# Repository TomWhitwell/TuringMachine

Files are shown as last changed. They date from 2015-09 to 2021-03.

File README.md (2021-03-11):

# TuringMachine Mark 2

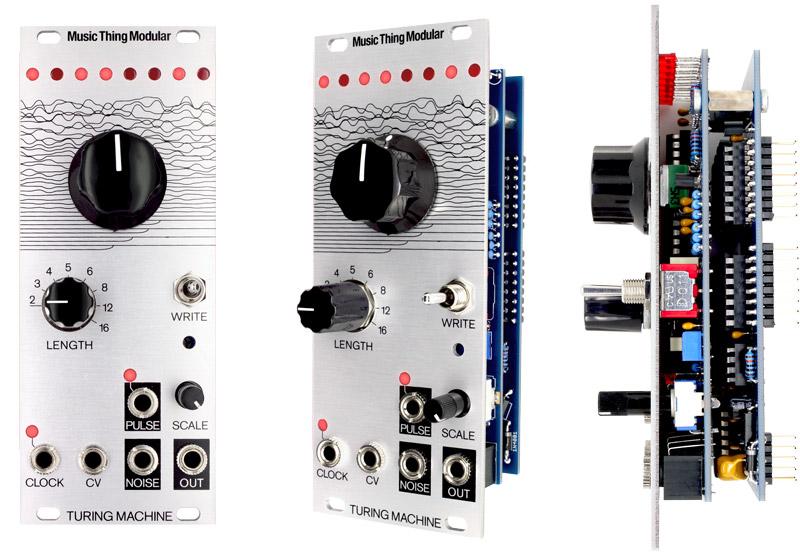
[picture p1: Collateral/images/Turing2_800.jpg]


Since it was launched in June 2012, the Turing Machine has become one of the most popular Eurorack DIY projects. It is a random looping sequencer that spits out basslines and melodies. It generates strings of random voltages that can be locked into looping sequences. 
These sequences can be allowed to slip, changing gradually over time. This module was inspired by the long history of shift register pseudorandom synth circuits, including the Triadex Muse, Buchla 266 Source of Uncertainly and Grant Richter’s Noisering.

[This video explains how the Turing Machine works.](https://www.youtube.com/watch?v=Le26BIqB8Y8)  

The 2016 revised Turing Machine has many improvements:  
- Rotary loop length switch 
- Pulse out
- Two boards, includes Backpack circuit to drive expanders (compatible with old Music Thing expanders)  
- Easier to build: a larger PCB in the same width, clock and noise circuits are more robust
- Noise level trimmer & reduced voltage in noise circuit to make circuit more robust with different noise transistors 
- Compatible with existing expanders 

*“I am interested in perceptible processes. I want to be able to hear the process happening throughout the music. To facilitate closely detailed listening a musical process should happen extremely gradually.”* Steve Reich, [Music as a Gradual Process](http://www.bussigel.com/systemsforplay/wp-content/uploads/2014/02/Reich_Gradual-Process.pdf), 1968. 

[Schematic](https://github.com/TomWhitwell/TuringMachine/blob/master/Collateral/PDF%20Schematics/TuringMachine2_Schematic_May2016.pdf)

Status:   
April 2016: Design files and Gerbers tested and prototyped successfully 

License:  
[CC-BY-SA](https://creativecommons.org/licenses/by-sa/3.0/)

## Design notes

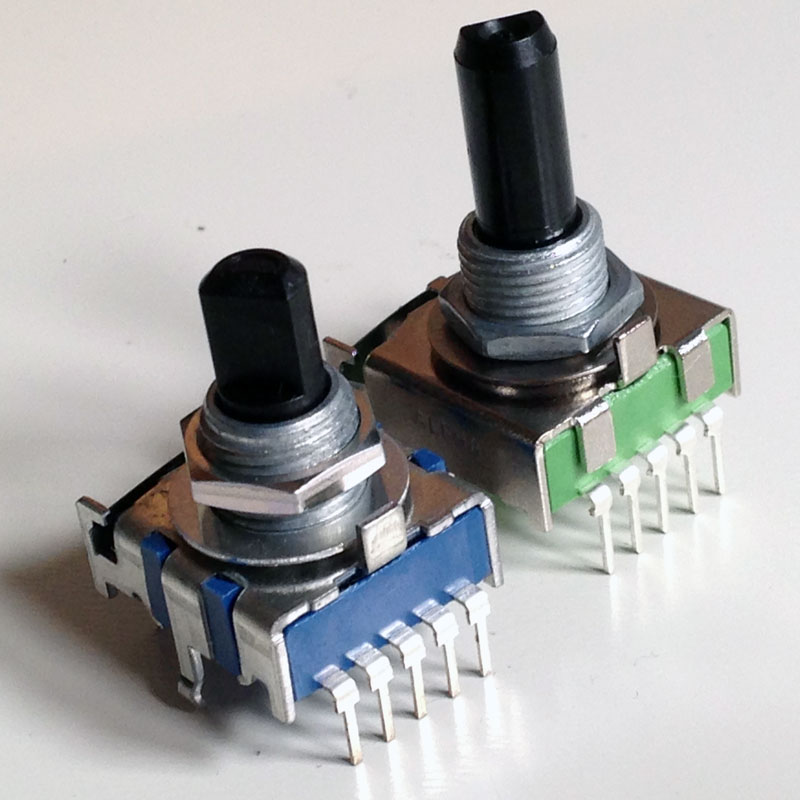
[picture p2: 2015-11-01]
Collateral/images/alps-alpha-switches.jpg

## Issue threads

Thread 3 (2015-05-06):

R5 is 51k on silkscreen, 50k on BOM

TomWhitwell, 2015-05-06:

TomWhitwell, 2015-07-25:
fixed

Closed 2015-07-25.

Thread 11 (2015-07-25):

Grounding issue - circuit only works with two cables, not one

TomWhitwell, 2015-07-25:
while in external case

TomWhitwell, 2015-07-25:
In external case

Closed 2015-10-24.

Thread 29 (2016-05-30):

Turing Machine won't power up.

stefanhelton, 2016-05-30:
Not sure what I may have done wrong, was hoping you could help me. After assembling the Turing Machine, I plugged it into a uZeus power module and nothing seemed to happen. When I sent a gate signal to the clock input and sent the out to an oscillator,  it triggered it in a continuous drone.  None of the LEDs are coming on, and none of the switches or potentiometers have any effect on the sound. Do you have any idea what my problem could be?

Thonk-Steve, 2016-05-30:
Best thing to start with is post some good photos of both sides of both boards.

stefanhelton, 2016-05-31:
Sorry if some of the board is hard to see, I'm having to do this from mobile and my camera isn't that great. Some of the solder points are a little sloppy, but as far as I can tell they all make solid contacts and don't bridge over to other solder points. I have access to a multimeter if that would help, I'm just not sure where to start checking.

stefanhelton, 2016-05-31:
Forgot the link to the pics, my bad

http://m.imgur.com/a/HUGIG

TomWhitwell, 2016-06-02:
The TL074 on the front board is upside down.
Curiously, I did EXACTLY the same thing while building a module this weekend. I spotted it, threw away the TL074 (you could probably just turn it round), got a new one, and installed THAT upside down too. Eventually I managed to put it the right way around (!) and it worked perfectly.

Closed 2016-06-02.

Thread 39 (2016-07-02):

diy osmosis

zaejin, 2016-07-02:
Hi, great fun building the kit but it seems there's a problem.
When it's attached to the power, it makes every socket in my modular output a clicky slow square tone.
Even on different modules. The other bits work okay when the turing isn't plugged in the power.

I'm using a synthrotek psu.
Cheers,
Victor.

Thonk-Steve, 2016-07-02:
I would start by using a multimeter to check if you have continuity on the
Turing power connector between -12v and Gnd, +12v and Gnd or +12v and -12v.

Sounds like you have a short circuit in the Turing build somewhere to me.
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

zaejin, 2016-07-02:
Hi thanks for your time.
There doesn't seem to be a short between those pins which I guess is where the whole of the circuit converges,
(i am a noob at this so I don't know where to look for shorts, those traces look awfully close).
I've had a look at all the solder joins and they seem ok.

Thonk-Steve, 2016-07-02:
Hi, do you mean you tested with a meter or visually? The short will present
itself at the header to the meter but physically could be anywhere on
either board. You can't do this test visually.
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

zaejin, 2016-07-02:
tested with a meter, yes. but I'm at passive mult level of skill here.

TomWhitwell, 2016-07-02:
I'd double check that all the chips are the right way round and in the right places

zaejin, 2016-07-02:
yeah they're checked to the build docs. all okay.

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

Thonk-Steve, 2016-07-04:
Ok I think best thing to do is take photos of both sides of both PCBs and
we can take it from there

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

zaejin, 2016-07-04:
Okay, taken some pictures as best I can without a tripod.
Many thanks for the effort.
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

swahananda, 2016-07-07:
It looks like your 1n4001 on the back board are both oriented in the same direction. This is no bueno as diodes only allow power to flow through one direction and your -12 rail is currently aiming back into your system. The one on the bottom left of your image needs to be reversed.

zaejin, 2016-07-07:
it works you f***ing wizard!! bit tricky resoldering the component but I managed it.
Thanks thanks thanks you efforts are appreciated thonk and friends.

Thonk-Steve, 2016-07-07:
Ah it was nice to come check up and find this :)
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

swahananda, 2016-07-07:
Oh heck yeah! Glad to be of some service! Now if only I can get my own Turings sorted, life will be even sweeter.

Closed 2016-09-15.

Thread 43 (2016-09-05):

No sign of life.

jestern77, 2016-09-05:
Assembled the complete kit as suggested in the docs. Seemed pretty easy. I plugged the TM (power + clock) nothing worked. Realized I forgot one 100nF cap on the ic (back) board. Soldered. Plugged in, no life. Checked all transformers to be correct and IC to be the right ones. Redid all solder points, still nothing. Sometimes when I unplug the power the two leds (clock and first bit) light up. Changed the TL074 (just in case) no sign of life.

Attached some pictures. Any clue? Maybe the lacking 100nF could have screwed up some IC? strange though...

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

TomWhitwell, 2016-09-15:
Can't see anything unusual in the pictures - have you made any progress? Does the clock LED flash when you connect it to a clock?

jestern77, 2016-09-15:
HI Tom, no unfortunately doesn't work. The led doesn't lit up but the noise output does output noise. So the power goes there. Maybe some burned IC?

TomWhitwell, 2016-09-15:
The clock input is the same chip as the noise generator, so it's hard to see how that could be. The 100nf would definitely not be a problem.
It's a mystery - are you able to try it in another case? Do you have a friend with a working Turing you could compare it with?
You could certainly try replacing the ICs, but it's an unusual case.

jestern77, 2016-09-15:
hmm I refilled some of the holes, still no sign of life. Checked the LED orientation. I can send it to repair to a friend and see what went wrong...

Closed 2017-12-19.

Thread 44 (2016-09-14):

Turing Machine mk2 error

paxxxx, 2016-09-14:
Hello guys! I just connect the turing machine mk2.

I put a square wave in clock , and the clock light its ok , same tempo than wave.
I get noise and pulse, but nothing comes from Out...i was following the calibrate video , and it seems that i should have sound from out isnt it?
Also... all the top lights are fixed all the time.

Anyone can help me on this?
thanks very much guys.
Picture attached.

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

TomWhitwell, 2016-09-14:
You won't get sound from Out, but voltages to drive an oscillator.

Lights will be fixed on until you put a clock in and put the main knob at 12 O'clock.

paxxxx, 2016-09-14:
Thanks for your reply Tom!

Now i connected the out to 1v Oct input of a synth, and then it sounds as loop...then i move the main knob at 12 o clock, and i see the lights moving , but after 2 or 3 compasses, all lights are gone and never come back!

Maybe im doing something wrong?? sorry if its a basic question.

paxxxx, 2016-09-14:
i mean, the clock still pulsing, but pulse output light are off now, and top lights are all off too.

paxxxx, 2016-09-15:
Nothing... The module accept the clock, and create some pulses and cvs, but after few seconds, all the top lights are off, the pulses lights are off, and dont create any cvs :(

TomWhitwell, 2016-09-15:
That sounds like a soldering error - somewhere you may have missed a pin, swapped a component or inserted a diode the wrong way around.

Closed 2016-09-15.

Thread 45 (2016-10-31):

Help appreciated with troubleshooting my build

mayk19, 2016-10-31:
I'm new to the modular world, just finishing my first 84hp rack. I love the idea of building something that I make music with so went for the Turing Mk2. Back in the late 80s I built my entire DJ setup from maplins kits, 100w mosfett amps, sound to light kits, cans for speakers and even cabs for citronics turntables (couldn't afford 1200s !)

However, a long time has passed since my last soldering forays and unfortunately my Turing doesn't work :-( bit of a cheepo soldering iron to start with so I'm thinking that's where the issues lay however, it powers up, all leds are lit (I need to re-confirm if clock is lit before I put the oscillator into it) but starting the Tuning procedure and there is no audio out at all. Can anyone help point me in the right direction to start trouble shooting? Failing that , is there a repair service out there at all ?

Pictures of my board attached.

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

mayk19, 2016-11-02:
I found a solder bridge between two pins on the IC "Shiftreg_Main" 4015 top two right ones. Waiting for a new chip socket to solder in as I couldn't get to the solder blob without removing the holder. Fingers crossed thats all it was.   Will update.

Closed 2017-12-19.

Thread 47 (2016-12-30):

Pulse outputs Failing

123gravy, 2016-12-30:
Hey,

 I have just put together the Turing machine plus volts and pulses expanders.  All working fine apart from the pulse output on the Turing machine itself and two outputs on the pulses expander (the '1+2' and '1+2+4+7'). There is no output from these at all. Has anyone experienced something like this? Or is there something I should try? Solder joints look ok

Thanks

TomWhitwell, 2016-12-30:
Check orientation of all the chips on the back PCB of the main Turing module. Try swapping the AND chips to see if that makes a difference

123gravy, 2016-12-30:
Hi Tom,

 Thanks for the reply.  Orientation of the chips are all good.  Which chips
are the AND chips?

Isn't it strange that both the 1 output and the 2 output are all good but
not the 1+2 output on the Pulses?

Cheers

On 30 December 2016 at 22:31, Tom Whitwell <notifications@github.com> wrote:

Check orientation of all the chips on the back PCB of the main Turing
module. Try swapping the AND chips to see if that makes a difference

—
You are receiving this because you authored the thread.
Reply to this email directly, view it on GitHub
<https://github.com/TomWhitwell/TuringMachine/issues/47#issuecomment-269761552>,
or mute the thread
<https://github.com/notifications/unsubscribe-auth/AXsIJGctYGebFNCVhT30W-qrve_1f9JZks5rNOucgaJpZM4LYHk_>
.

Thonk-Steve, 2016-12-30:
Photos of the build would help, did you also double check the soldering of the expansion header on the main module? Do you have any other expander modules like Volts, Voltages etc?

TomWhitwell, 2016-12-30:
You can also try connecting pulses to the gates header. That will tell you if the problem  is in the main module, or the pulses module.

123gravy, 2017-01-04:
Hi,

 Thanks for the replies.  Please excuse my slow reply, I was away from my rig for a few days.

I do have another expander, Volts.  Seems to be working ok.

The solder joints of the expansion headers look ok to me but I'll attach a few photos.

I attached the Pulses module to the Gates header on the Turing Machine and the Pulse output on the Turing Machine then works, but still not the two (the '1+2' and '1+2+4+7') outputs on the Pulses module.  What does that suggest there must be an issue with both the TM and the Pulses builds?  Sorry to be a pain

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

123gravy, 2017-01-04:
I double checked all of the expander headers and re-soldered a couple of pins that looked as though the solder hadn't gone through to the other side quite as well when you pry up the black pin support on the header.  Still all the same

123gravy, 2017-01-04:
I've checked all of the jacks on the Pulses with a beep test.  All fine.  Re-soldered the IC as it was a bit rough.  Still the same.  I'm convinced that it is just the Pulses module.  I just can't suss out which component...
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

123gravy, 2017-01-05:
The Pulse output on the Turing Machine also works fine without any expanders attached

123gravy, 2017-01-10:
I should also mention that the outputs of the Pulses do not carry pitch but they do give a signal.  I've been using them to trigger drums which works fine.  However when I send the signal to an oscillator they each trigger in only one pitch.  Every output has the same pitch except for output 1 which has a higher repeated pitch, no variation following the turing machine...

TomWhitwell, 2017-01-10:
Pulses outputs are triggers - normally low (below 1v) becoming high (roughly 8v) when they are active. They're not expected to have any pitch content.

123gravy, 2017-01-10:
Ah ok. I only got that impression from this video https://youtu.be/Le26BIqB8Y8 about 14 mins in. I can't see the full patch though.  So that's that query sorted. Thanks. Can you make any sense of the rest. (The 2 outputs not working on the pulses and the pulse output not working on the Turing machine only when the pulses is plugged in)?

TomWhitwell, 2017-01-10:
Sounds like a soldering problem around the chip on the expander

123gravy, 2017-01-10:
Ok cheers. I did touch up some soldering around the chip and nothing changed. It still could be better though so I'll try removing it altogether and starting fresh. Thanks

123gravy, 2017-01-10:
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
Hello again Tom.  OK so i re-soldered it again and this time also lost outputs 4, 2+4, and 4+7.  I touched it up again and managed to get it back to just missing the original 1+2 and 1+2+4+7.  As you can see from this photo I've made a dogs dinner of the PCB.  You can see some copper next to the IC.
 I'm wondering maybe if I've knackered the IC? Or now possibly the PCB?  Or both.  Would it be worth getting a new IC do you think?  Or have I killed this one?  Sorry to be a pain in the arse

TomWhitwell, 2017-01-10:
Hi, - that doesn't look great - I can't really tell from the pictures, but it looks like there could be any number of shorts between the IC pins. If you have access to a hot air soldering gun, lots of flux and soldering braid, it might be possible to clean it up, but tricky...

123gravy, 2017-01-10:
I do have a bit of flux and braid.  Yeah to be honest I haven't really been using the flux.  I'll give it a proper go again using those.  So you wouldn't be too worried about the exposed copper on the PCB?

TomWhitwell, 2017-01-10:
If it's just exposed, that's probably OK so long as nothing is shorting onto it.

123gravy, 2017-01-10:
Ok, thanks

123gravy, 2017-02-01:
Hey Tom,

 Cleaned up the IC.  Re-soldered like a machine! Same drama.  Re-soldered all resistors.  All working like a dream, Turing machine, volts and pulses.  Must have been a bad contact thing with the resistors on the Pulses.  Awesome kits! How annoying is ametures must be.  Cheers

Closed 2017-02-01.

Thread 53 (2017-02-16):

BOM xls missing 47k resistor

whodevil, 2017-02-16:
Hello,

I'm looking over the BOM and the PCB, and it appears as though the mouser BOM that is in xls format is missing a 47k resistor.

Thanks!

Thonk-Steve, 2017-02-16:
Hi, which BOM?

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

whodevil, 2017-02-17:
Hello, this is the one I'm talking about /Collateral/BOM/Turing v4 Mouser Export.xls
I think it is also missing two 1n4001 diodes and two ferrite beads.

whodevil, 2017-02-17:
It seems like this BOM is for a different project than the Turing Machine MKii. Here is what I have found missing so far:
- 47k resistor
- 2.2k resistor (9x)
- 1n4001 diodes (2x)
- two ferrite beads
- two fuses
- 78L09 voltage regulator (2x)
- 6 pin two row female socket (2x)
- 10 pin two row female socket
- 16 pin IC socket (x5)
- 14 pin IC socket (x4)
- 8 pin IC socket
- .1uf ceramic capacitor (8x) - There are 5 in the BOM but the build requires 13
- 100n ceramic capacitor (5x)
- hex stilts (2x)
- IC CD4050 (2x)
- IC CD4081 (2x)

There are 3 TL072 but only one is required.
There is an extra 10k resistor.
There are three 2N3903 transistors but only one is required.

It would probably make more sense for me to fix it and create a pull request.

Thonk-Steve, 2017-02-17:
Ah ok, yeah use this one - https://docs.google.com/spreadsheets/d/1FUUejrNd6qe-PUmlLi0BAgiGKWX9DxQH3Jt5qFOxPAQ/edit?usp=sharing

whodevil, 2017-02-17:
@Thonk-Steve Thanks! I think that document should be linked in the README.md or something. At the very least remove the old BOMs from the repo.

TomWhitwell, 2017-02-19:
Thanks, have now updated with a link to the correct BOM from Google Docs

Closed 2017-02-19.

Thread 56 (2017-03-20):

No sound at output, no action on Leds

zoth4355, 2017-03-20:
Bought the turing from Thonk (complete kit with volts and pulses). The unit worked for months, then I sold to a buddy. Worked fine until a couple of weeks ago. The unit stopped locking and the seq leds  stalled, clock input doesn't seem to move anything or when it does it hangs almost immediately. He brought it back to me to check it out. Tried clocking it from 3 different sources (ALM's Pamela's, 4MS QCD and an SSF Square Wave. clock LED seems to work (does flicker), pulses LED is always lit (?), noise output works, and I hear nothing from the output (found this while calibrating the unit). I'd appreciate some help resolving this issue. Thank you.

TomWhitwell, 2017-03-20:
If it was working but is now not working, could it have suffered some strange voltage incident; it's protected against reverse voltage, but could have been something else. Swapping the chips would be one way to find out, start with the TL074 on the front PCB - that handles the clock. Alternatively- could it be a cold solder joint somewhere?

zoth4355, 2017-03-20:
Swaped the TL074, did get some action for a couple of second then stopped. I tested the scale knob and it does work, but the sequnce hang hafter little time, odd. I'll go back to my solders, hopefully it's a cold joint. Thank you for the super fast reply Tom.

TomWhitwell, 2017-06-21:
Hi, did you make any progress with this?

zoth4355, 2017-06-21:
Hi Tom,
Thanks for asking,
I've tried every trick in the book, reflowing the solders, recalibration and swapping some IC's and other stuff, still unstable, sometime locked for 10-15 mins when lucky (this was tested without the expanders attached). I got frustrated and bought new pcb's from Steven and ordered new components from mouser. The original unit, I think, had a bad trace but I can't confirm, I just couldn't find what went wrong, why it got crazy after a few month of working properly. 
Sold the fresh new unit to a buddy. Still stable at this time. All IC's are TI went for quality parts, took more care than usual when manipulating the pcb's and advised my friend to be careful when connecting the pulses and voltages. Now he want's me to order and build a vactrol mix for him... 
Might it strain the Turing module to have so many expanders attached to it? Don't see why but might as well ask.
Thanks
Pat

    Le mercredi 21 juin 2017 3h10, Tom Whitwell <notifications@github.com> a écrit :

 Hi, did you make any progress with this?—
You are receiving this because you authored the thread.
Reply to this email directly, view it on GitHub, or mute the thread.

Closed 2017-12-19.

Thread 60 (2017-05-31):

No Clock LED, No Output, build not working

bertog, 2017-05-31:
Hi,

I've just finished my second TM build and this time I've some issue. The module power up but when I plug the square signal in the clock input there's no LED activity or audio output (seems something but very very very low). The DAC0800 become also immediately very hot. Some advice to begin some trouble shooting?

Some picture of my build:

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

Thank you very much. Guido Bertolino

Thonk-Steve, 2017-05-31:
Do you still have your successful build?
Have you checked with a multimeter for a short between +12v and gnd, or -12v and gnd?

bertog, 2017-05-31:
Hi Steve,

Yes I've access to the other build.

I've checked now and I've no short.

G.

Thonk-Steve, 2017-05-31:
I would suggest trying a combination of front and rear PCBs with the working build, then at least you can find out which board is faulty? You tested for shorts with the defective PCBs mated together?

bertog, 2017-05-31:
Thanks for the help.

I've matched the rear PCB of successful build with the jack pcb of the faulty and everything is working. I've successfully calibrated the module.

So the problem is on the rear PCB.

I've check for short with the mated PCBs and now only on the rear, but seems there's no shorts

G.

bertog, 2017-05-31:
Ok Steve,

I've founded the problem ... there was a small piece of lead touch one of the IC solder joint ...

I've removed it and now is working ...

Sorry and thank you very much for the help ... I'm newbie so I fall in panic very early, but tonight I've learned some troubleshooting ... Thanks again :) Guido

Thonk-Steve, 2017-05-31:
great, just talking about and trying new angles often shakes these things out :)

Closed 2017-06-21.

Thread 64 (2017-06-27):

Clock LED doesn't trigger and all lights come on at the top, don't change.

calmoo, 2017-06-27:
So i finished the build today. I've double checked all components and solder joints.

When I turn it on, all the lights at the top of the Turing Machine come on. The clock LED doesn't respond to a clock source at all. Sometimes when I turn it on, the top left LED stays off while the others stay on. The knobs don't change anything. The noise output works.

Not sure what I'm missing?

TomWhitwell, 2017-06-27:
Check around the TL074 on the front board - that's the clock circuit - it's possibly a missed solder point there or on the clock input. If noise is working, then that TL074 is working - receiving power etc, so it's likely to be a missing solder joint or component.
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

calmoo, 2017-06-27:
Figured out that the clock source I was feeding from my phones LFO
generator volume  was too low. Daisy chained it from a doepfer envelope
generator and it worked a charm. Thanks Tom!

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

Closed 2017-08-03.

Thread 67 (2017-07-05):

can't calibrate, get a kind of sinus sound...

Latzenpratz, 2017-07-05:
Hi!

just finished my build. I'm trying to calibrate, but the main pot and the calibration pot don't do anything. Length, write and scale seem to work. I here something like a sine wave played with  the set length, but no randomness.

Thonk-Steve, 2017-07-06:
Would it be possible to upload a video demonstrating your problem?

On Wed, Jul 5, 2017 at 8:22 PM, Latzenpratz <notifications@github.com>
wrote:

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

Latzenpratz, 2017-07-06:
Thanks for the quick response!
I'll try to make a video next weekend...

Latzenpratz, 2017-07-13:
Hi!
I noticed that the Turing triggers my maths without connecting it (i can hear the turing output from the maths output). The only connection between them is the power board...
So i'm to scared for now to reinstall the turing and make a video.
Maybe you can see an error on the pics:
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

Latzenpratz, 2017-07-21:
On my MDLR busboard the -12v LED doesn't light up if i install the turingmachine, so it seems there is a short-circuit or something... help...

Thonk-Steve, 2017-07-21:
Use a multimeter continuity tester to see if you have continuity between:

+12v and gnd
+12v and -12v
-12v and gnd

On Fri, Jul 21, 2017 at 4:05 PM, Latzenpratz <notifications@github.com>
wrote:

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

Latzenpratz, 2017-07-21:
yes, continuity between -12v and gnd

Thonk-Steve, 2017-07-21:
yeah I would start looking along the -12v lines and see if you have any
shorts

On Fri, Jul 21, 2017 at 4:11 PM, Latzenpratz <notifications@github.com>
wrote:

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

Latzenpratz, 2017-07-21:
yes the short must be on the board with the music thing print. i'll do my very best ;-) THANKS!

Thonk-Steve, 2017-07-21:
yeah it is worth taking the PCBs apart just to double check which board
it's on.

On Fri, Jul 21, 2017 at 4:16 PM, Latzenpratz <notifications@github.com>
wrote:

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

Latzenpratz, 2017-07-21:
I can't see any visible short, where are good points to break the circuit to narrow down the place of the short?

Latzenpratz, 2017-07-25:
Found it!  :yay:
One diode was faulty, after removing it the turing machine works!

Closed 2017-07-25.

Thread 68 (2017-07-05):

No Random output

Paulhamlin, 2017-07-05:
Hi Tom / Thonk

Thanks for putting together a great build with instructions, its been a breeze up untill now. I've come to the end of my build and all appears to be working well and behaving as should apart from the random voltage out. The scale knob adjusts pitch correctly and the lights displaying the cycling of notes however the outputted pitch is always the same.

Have you any ideas about this or where would be a good place to start looking? Ive double checked solder joints and will triple check in the morn just to be sure.

Thanks
Paul

Thonk-Steve, 2017-07-05:
Hi Paul, is the white noise output working?

Paulhamlin, 2017-07-06:
Hi Steve, thanks for getting back to me - yes im getting white noise when connected directly to an output.

Thonk-Steve, 2017-07-06:
Hi Paul,

Is the white noise output a relatively 'normal' volume level? not super
quiet or anything?

You're sending the main output to the 1v/oct input of an oscillator to
test? what are you clocking it with?

Steve

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

Paulhamlin, 2017-07-06:
Yeah the white noise level seems good.

I'm clocking with maths that is going into the 1v/oct on braids. Just metered the output with the scale knob on zero and the module cycling and the output shows a steady 0.00v - moving the scale knob moves this voltage up however there is no fluctuation in voltages.

Cheers

Paulhamlin, 2017-07-06:
Spent a few hours earlier today checking over the board / checking for shorts and making sure that i didn't put anything in incorrectly and I'm still getting the same behaviour.

From looking over the schematic it looks like the DAC chip is responsible for the output, could it be possible that its faulty? Ive searched high and low on the Muffwiggler forums and can't seem to find anyone else with this problem...

Any help or advice would be much appreciated!

Thanks

TomWhitwell, 2017-07-13:
Sounds like a problem with either the DAC or the TL074. If you have the clock and noise working, they're both on the TL074, so it points to the DAC, or the surrounding infrastructure: the TL431 voltage reference, R28, R27, C9, R26.
Completely unchanging output means it's not getting partial data, so the 8 data lines into the DAC can't be the fault. Could be a bad DAC chip, or a soldering error  / short somewhere around there.

Paulhamlin, 2017-07-19:
Hi Tom,

Thanks for the advice - managed to solve it after metering between the parts you listed.

Turned out a pad had somehow got damaged and wasn't flowing to the PCB solder - putting a cable link in got it up and running, not the prettiest but got it working correctly!

Thanks again
Paul

guidozzz, 2019-01-20:
Thank you Tom (and Paul for starting the thread with exactly the same issue as me) !
A connection between R27 and TL431 wasn't working. I have done a wire link and seems to work fine now!

Closed 2017-07-19.

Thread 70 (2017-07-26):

Led B4 not working

Rolf102, 2017-07-26:
Hi,

I finished my Turing machine mk2 today it is working perfectly except for one led, i checked the schematic, it is led B4.
I tested the LED it is not broken, i reflowed all the joints on both boards with no effect.
While it is a minor defect the perfectionist in me cannot overcome this.

Please help

TomWhitwell, 2017-07-26:
Did you check the LED is not reversed?

Rolf102, 2017-07-26:
unfortunately no all the leds are in the same orientation

Rolf102, 2017-07-27:
i checked all the components and found that i soldered one of the 78l09 with the flat face to the wrong side, i fixed it but the led still does not light up, should i replace the 78l09 for a new one?

Thonk-Steve, 2017-07-28:
do you have a multimeter? can you check if the new 78l09 is putting out 9V?

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

Rolf102, 2017-07-29:
both voltage regulators are putting out 9 volts

Rolf102, 2017-07-29:
i fixed the problem, the trace from the led negative pole to the resistor is broken.
i soldered a copper wire from the led to the resistor

Closed 2017-08-03.

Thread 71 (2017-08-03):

TuringMachine not working at all

dorkajef, 2017-08-03:
Hello,
Finished My DIY for the Turing machine yesterday. But it did not show any traces of life -> no noise, it did not blink lights, did not effect the OSC when patching, did not react to clock signal.
I did check My solders couple of times, double checked also the parts -> everything should be ok (but after one check the upper light when on ((but no reaction to clock, etc...) -> and when I unplug the device and put all the nuts on -> again no lights.
I know that My solder is not the best A+, but all My DIY units have worked until now.
Would you have an idea what´s wrong?

Best Regards
Thomas
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

TomWhitwell, 2017-08-03:
Hi, sorry to hear that. When I have problems like that, it's often because I've done something extra stupid - like not turning on the power, not connecting the other end of the power cable etc.
One thing you could try is - if you have  multimeter - checking that you're getting the appropriate power to the chips - i.e. separate the boards, plug the back board into power, and check there is (roughly) 24v difference between pin4 (black probe) and pin8 (red probe) on the little TL072. That will tell you if there's a basic problem with power. If the back board is OK, carefully check the soldering on the connector pins between the back and front boards - if the front board isn't getting any power, you'd get the symptoms you describe.

dorkajef, 2017-08-03:
Thanks Tom for the Quick answer.
Gonna try that tonight after I come home.
Best
Thomas

dorkajef, 2017-08-03:
Hello,
I think I may found the problem. There is a shortcut in the six pin header (the middle one on the back board). Could this mistake have fried my parts?
Thanks!
-Thomas

TomWhitwell, 2017-08-03:
Possibly not - that connects +12 to -12v, which I'd imagine would cause your case power supply to shut down quite fast - fix it, check there's no more connectivity, and test to see

dorkajef, 2017-08-03:
Hi,
Just to make sure that we are speaking from the same part...
I removed the connection part, and try to clean the area, but if I assume right the PCB has jumpers between pins 1&4, 3&6, and on the other side 2&5 (but I quite n00b with these things;).
I´m just wondering because my meter is beeping with these connections (also with the upper PCB).
Best Regards
Thomas
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

TomWhitwell, 2017-08-03:
This is how they're connected:
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

dorkajef, 2017-08-03:
Sorry my bad, I did mistakenly assume who those are counted -> so no shortcut there, they where as they should be.
I did also measure the power as You instructed -> and I got a reading of about 25 Vdc and 52 Vac.
Did also solder all the connector pins newly (at that moment I mistakenly noticed that so called shortcut). So any ideas?
Best Regards
-Thomas

dorkajef, 2017-08-03:
Hi,
I did also test the connection pins while the boards are connected, the connections works - but I also noticed that on the upper board has also an connection beteeen +12 & GND somewhere (this is normal, I suppose).

-Thomas

TomWhitwell, 2017-08-03:
No, there shouldn't be a connection between +12 and GND - that would also the problem.

dorkajef, 2017-08-04:
Ok, I´m on the trace.
I did try to find out where the GND goes (but can´t see it from the PCB), and I´m not enough seasoned to read it from the schematics. So if you can advice Me (then I maybe could find the shortcut).
Thanks
-Thomas

TomWhitwell, 2017-08-04:
GND lives on the ground plane - it's all the copper on the bottom that isn't part of another trace:
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

dorkajef, 2017-08-04:
Ok, thanks.
So non of the GND points should make a connection with +12?
-Thomas

TomWhitwell, 2017-08-04:
Definitely not

dorkajef, 2017-08-04:
Hi,
Have been looking for any solder shortcuts (could not find any). I even removed some parts (all capacitors but not: c17, c14 & c9).  The IC´s I removed in the beginnin of this operation.
Still a shortcut when measuring Link2 pins 6&4 (+12 & GND).
Any idea where / what path I could try to find next?
Thanks for the help.
-Thomas

TomWhitwell, 2017-08-04:
Do you think the back board (with the power connector) is OK? Is that's where you tested the PCB voltages on the TL072?

Separate the boards, remove the two ICs from the front board, and see if there is still a short between +12v and GND

dorkajef, 2017-08-04:
Yes that is what I did. I assume that the back board was ok (measured the voltages as described -> ok), the pins had no short between the pins (when measured the back board separate)- > So I´m quite sure the problem is on the front panel.

Closed 2017-12-19.

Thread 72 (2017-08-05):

Short around power input.

foenzie, 2017-08-05:
Hi Mark,
First of al this is a great kit to build. Very clear documentation! But somehow i messed it up a bit. After finnishing the module I connected the power the wrong way around.. but only for like 2 sec. Then I connected it the right way around. Smoke started coming between the  +12 volt and the big fuse pcb trace. Elektricity finds the shortest way right, after measuring, there is a short between al ground and +12 volts. I cannot find any shorts on the board. Removed all IC and top board. Still shorts. I suspect the 10 pin power is somehow shorter, but all grounds to +12 seems unlikely? Thanks in advance. Funs

_Sent from my OnePlus ONEPLUS A3003 using [FastHub](https://play.google.com/store/apps/details?id=com.fastaccess.github)_

foenzie, 2017-08-05:
In my frustration I cut both rectifying diodes and one bi-polar capacitor. On this picture is clearly seen where the short is.

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

foenzie, 2017-08-06:
Hey Tom,

After some troubleshooting the board some more I found my short. In the picture below you can see exactly what part is shorted to ground. I strangely enough could not find any visual conformation from this short.  After cutting the PCB trace I found out this part was shorted and made a simple bypass (Removing all power pins did not remove the short). The Diode and fuse are fine I don't know how this is possible. But anyway thanks for the possibility to ask questions!!! Keep on building!

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

Closed 2017-12-19.

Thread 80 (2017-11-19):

Module partially not working

Stahlmotte, 2017-11-19:
Hi,
first of all: I´m not an expert in DIY modules. :-) So it would be great to get a little help. Maybe this is also something that happend in the past and a quick fix.

At the moment noise out works and all the LEDs (besides the first one) in the top row are on permanent. Nothing else is happening.

I checked for solder joints and stuff like that. I also checked the placement of the items. No luck so far.

So a little help would be great!!

Thanks in advance

Alex

TomWhitwell, 2017-11-19:
Hi Alex, sorry to hear that.
What are you using to clock the module?

Stahlmotte, 2017-11-19:
Hi Tom,
thank you for the quick reply. I tried a the Black VC Clock Module von Erica Synth and also Clock signal via uMidi. Anyway, sending a clock signal does not change the behaviour anyway. With or without clock signal.

TomWhitwell, 2017-11-19:
So your issue might be around the clock input - if the clock in doesn't flash the LED above the clock socket, that is definitely the place to start looking - check for missing solder joints or IC in the wrong way around.
I've often built a whole module, found a weird fault, then discovered I missed a couple of solder joints on sockets or ICs.

Schematics are here: https://github.com/TomWhitwell/TuringMachine/blob/master/Collateral/PDF_Schematics%20/TuringMachine2_Schematic_May2016.pdf
If the noise output is working, then the TL074 is alive (i.e. connected to power and the right way around) so it could be a connection to it, or one of the other components.

Stahlmotte, 2017-11-19:
Hi Tom,
tried to find all faulty solder joints in the last days and also today. Sure, i might be missing something. :-) Anyway, do you think it could be also a faulty IC? Thinking of ordering and swapping them if this could also be a possible option.
Best
Alex

TomWhitwell, 2017-11-19:
If you don't get a flashing LED above the clock in when you input a clock, that along will mean the rest of the module won't work - everything else could be perfect. The only IC involved in making that LED flash is the TL074 on the front board, and if you have noise, that IC is at least partly working.
In short - I think there's a faulty connection or a misplaced component somewhere here:
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

Stahlmotte, 2017-11-20:
Tom,
thank you again for your help. I really appreciate that! Yesterday i resoldered several joints on the board. Now, when powering up the module the LED flashes once at least. Everything else is still the same, but i will try to wirk through all the joints again. Hopefully this is the solution!
Best
Alex

Closed 2017-12-19.

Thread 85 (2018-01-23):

Powers on but not much else

schrickvr6, 2018-01-23:
Hi Tom,

I'm a relative noob to DIY and modular so please bear with me, I bought panel and PCB so there's every chance I've bought an incorrect part.

Basically it powers on ok, it may be inconsequential but sometimes all of the top row of LED's light up and sometimes a few don't. I'm getting no output (except a tiny bit of noise when I adjust scale), no movement or randomness but most tellingly it seems no input on clock, I've tried a square wave as in the calibration video and a gate from a beatstep with no response or clock LED activity.

In the way of fault finding I've reflowed everything, reseated IC's and swapped matching pairs, I've also measured all the resistances which tally with marked values except R10 which measured 83k instead of 100k, but various people on Facebook have reassured me that should be normal.

Any thoughts on where my problem may lie or how I should start/continue fault finding?

Cheers.

schrickvr6, 2018-01-25:
Please ignore (for now), I'd fitted a 68ohm instead of 68k right next door to r10, I don't have a spare to confirm this is my only issue but will close this if it works when my resistors arrive.

TomWhitwell, 2018-01-25:
Sorry to hear this, Yes, R10 as 68R vs 68K that would do it - I was going to suggest you look at the TL074 on the front board, but if you're pulling the clock to GND you won't get much joy.

Closed 2018-01-25.

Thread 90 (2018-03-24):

expander pulses 5 always pulsing, just like the clock source

indraperkasa, 2018-03-24:
Hi, i've built my turing machine and all the expanders few months ago, and its been working just fine. until recently i just noticed my pulse expander, on the pulse 5 is ticking exactly like the clock input on the main turing machine. from my understanding, it shouldn't do that (or am i wrong?).
the rest of the pulse working normally, have the same LED movement just like the LED from the main turing machine. i have all expander connected to the turing machine.
i try to switch, connecting the pulse expander to the gate connector (instead of pulse connector) on the back of the turing machine, and it work normal, the LED on turing machine reflected the same movement like in the pulses expander. so i suspected, there's a problem in the pulses connector at the turing machine, but i don't know what to do about it.
any idea what is broken? or maybe should i replace any IC?

thank you.

jstamant, 2018-03-24:
@indraperkasa Very good troubleshooting on your part. From what you're telling us, I'm comfortable in saying that there's no problem with the pulses connector.

Here's what I'm suspecting:
- Pulse 5 is shorted to 12V
- One of your 4081 quad AND gate ICs are defective.
- One of your 4015 shift register ICs are defective

Is the 5th LED on the Turing Machine always lit?

Try swapping the two 4081 ICs on your Turing Machine to see if the problem moves from pulse 5 to pulse 3. If it does, the 4081 that had pulse 5 on it is defective.

You can also try swapping the two 4015 ICs to see if that clears the problem.

If after you've swapped the two 4081 ICs, and the problem still registers on pulse 5, you'll have to start checking some voltages and continuity. First check the continuity on all the pins of the 4081 quad AND gate chip that carries pulse 5. Make sure that each pin on the chip has continuity to where they're supposed to go, and not connected to +/-12V or ground if they're not supposed to. Pin 8 on the 2nd AND gate IC (closest to the board edge) should have continuity to pin 4 on LINK3, pin 13 of the main 4015 shift register IC (closest to board corner), and should NOT have continuity to the +12V rail.

If all that still doesn't shed some light on your issue, check the voltage on pulse 5's AND gate inputs. Sounds like pin 8 with the B4_BACK signal is stuck high, and is just passing through the clock.

indraperkasa, 2018-03-25:
@jstamant hi Justin, thank you so much for the quick response.
the 5th LED on turing machine doesn't always lit, only on the pulses expander.
another thing i noticed, if i hold down the toggle write switch, all the LED goes off, except the LED 5 on the pulses expander, which pulsing at the same rate with LED clock input at the turing machine.

i've tried swaping the the two 4081 IC, didn't make any different. same result with the swapping of the 4015IC.
forgive me, since i'm a very newbie, don't really know about this electronical stuff, just got into soldering when i start to play modular a few months ago. i don't really know how to check voltages and continuity. if you don't mind, maybe can you guide me? i have a digital multimeter. i've been youtubing on how to do it, just not really sure if i was doing the right thing.
let say, if the Pin 8  on the 2nd AND gate IC4081 doesn't have continuity, what should i do next?

and about your last suggestion, can you guide me how to do it? checking the voltage on pulse 5's AND gate input (i don't know which one..). and if the pin 8 with the B4_BACK is stuck high, what should i do next?

thank you.

jstamant, 2018-03-25:
No worries, @indraperkasa.

You'll need to refer to the [schematic](https://github.com/TomWhitwell/TuringMachine/blob/master/Collateral/PDF_Schematics%20/TuringMachine2_Schematic_May2016.pdf) for the remainder of your troubleshooting. Also, downloading Autodesk's EAGLE will let you open the `*.brd` files located [here](https://github.com/TomWhitwell/TuringMachine/tree/master/Hardware) to get an x-ray view of the board, which you might find helpful for troubleshooting.

When you're checking continuity or checking resistance between two points, you need to have the board powered off. With your multimeter set to measure resistance, touch the two probe ends together, and make sure the multimeter reads close to 0 ohms. Next, take a spare resistor and measure its resistance. If the multimeter is reading the right value, then you know your multimeter is working, and you can proceed to checking continuity and voltages.

Again with your multimeter set to measure resistance, touch one probe to pin 8 of 4081 IC closest to the board edge, and touch the other probe to one of the +12V pins on the power header (opposite end of where the red strip goes). The multimeter should read "OL" or something similar indicating that the two points are not connected. Then do the other resistance/continuity checks with the other pins I mentioned. i.e. from pin 8 to LINK3's pin 4, and from pin 8 to pin 13 of the 4015 IC. All these pins are connected, so they should read something close to 0 ohms on your multimeter. Sometimes you have to press the probes hard to penetrate a thin layer of oxidization and/or flux to get a reading at all.

After you've done that, you can check voltages with the board assembled and powered on. Keep the front panel off the Turing Machine until you've confirmed that it's working. This time, to check that your multimeter reads voltages correctly, measure the voltages at the power header, because you *know* it carries +/-12V and 0V, or your module wouldn't power on. Placing the black lead on a GND pin, and the red lead on a + pin should read 12V. Then trying the red lead on a - pin should read -12V. Good, now you've confirmed that you multimeter is fine. Keep the black lead on the GND pin, and place the red lead on pin 8 of the 4081IC that's closest to the board edge to check the voltage on that pin. It should read 0V if there's no pulse on LED 5 on the Turing Machine. It should read 12V if there IS a pulse on LED 5 on the Turing Machine. From what you're telling us, it sounds like the voltage is *always* 12V, but we need to confirm that by measuring it.

indraperkasa, 2018-03-26:
@jstamant hi Justin,
thank you so much for writing this step by step, really appreciated it.
i did some test based on your guide.

the results are:
pin 8 of 4081IC closest to the board edge to +12v = approximately 6 mega ohm
pin 8 of 4081IC closest to the board edge to LINK3's pin 4 = approx. 18 mega ohm
pin 8 of 4081IC closest to the board edge to pin 13 of 4015IC = approx. 6 mega ohm

and with the board assembled and powered on,
pin 8 of 4081IC closest to the board edge with ground pin, reads 0v when LED 5 is off on turing machine, also reads 0v when the LED 5 is on.

indraperkasa, 2018-03-26:
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
just to confirm if i did test the right pin, here i attach the photo, i put the red circle for the pins that i think the one that you refer to..i hope its the right

jstamant, 2018-04-01:
@indraperkasa How confident are you with your use of the multimeter? The pins you outlined in your picture are the right ones, so you were taking measurements on the correct pins. I was hoping on getting different results than you indicated, though.

I was expecting pin 8 of the AND_2 chip to be either shorted to the +12V rail, or at least showing a voltage >+8V at all times (the 4081 IC closest to the board edge is named AND_2, the other 4081 IC I don't care about is named AND_1). You indicated that the pin shows a crazy-high resistance to +12V, meaning they're not connected, and that the pin is always showing 0V while running. If that pin shows 0V, then LED 5 on the Turing Machine should be off. Whenever it shows a voltage, LED 5 on the Turing Machine should be on.

Then, pin 8 of the AND_2 chip is supposed to be connected to LINK3's pin 4 and pin 13 of the main 4015 shift register, i.e. showing ~0 ohms. According to your measurements, in the mega-ohms range, they're not connected.

Let me know what you think of these results.

indraperkasa, 2018-04-02:
hi Justin,
i'm pretty confident with the result form the multimeter, i've checked it several times and the result is pretty much the same.
however there's bad news, i might damaged the module during the testing voltage procedure. i accidentally put the black lead from the multimeter (slip from my finger) in the -12v pin, and it causes spark a few times.
now, when i try to input a clock, the LED on turing machine doesn't even do random pattern anymore. it still receive clock pulse, but when i hold down the write toggle, after all the LED off, it remains off all the time. also if i hold up the write toggle for once, one LED show up, but that's it, only that one LED run across the all the 8 LED, looping.
i've been thinking, maybe just gonna let this one go..

jstamant, 2018-04-02:
Ok, no problem: a little spark is nothing we can't fix.

Where did you short the two pins? On the power header? Or was it one of the ICs? If you shorted on the power header, the damage would sooner be to your power module. If you shorted on an IC pin, that IC could be blown.

Did the spark appear on your test lead, or was it a component that sparked? Did you smell smoke when this happened? Magic smoke is the telltale sign of a failed component.

As for measuring the voltage on LED 5, that suggestion is still applicable. You can still check the voltage on that. It sounds like you can also troubleshoot the original issue with pulse 5 regardless of this other issue.

indraperkasa, 2018-04-02:
the sparks was on the power header. and it did make my power module to stutter, the +12v led lights blinking rapidly for a moment, and then back to normal.
thanks so much for the suggestion, i'm gonna try it again.

indraperkasa, 2019-06-13:
hi, just wanna say i finally solved the problem after abandoning it for more than a year. turns out the pin 8 iC 4081 (close to the edge) didn't connected to where it supposed to, turns out there's a scratch in the pcb, that broken the Via connection. so i solder a wire from pin 8 IC 4081 (close to edge) to the pin 5 IC 4050 (close to the edge). and now its working.
just wanna say thanks for your help, i learnt alot from debugging this, i feel a little bit confidence now on troubleshooting. and i'm getting more familiar with eagle file, such a convenience way.
thank you.

TomWhitwell, 2019-06-13:
So glad to hear it worked, @indraperkasa

Closed 2019-06-13.

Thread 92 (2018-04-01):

Turing Machine Dropping Notes + LED 2 out

BlipSqueek, 2018-04-01:
I have 2 issues with my build. I have built many modules so I'm not new to this, but I am also not someone who is good at troubleshooting circuits.
1) LED2 is out, but I do appear to be getting notes from 2
2) The turing machine will drop notes. If I have the main pot at around 3-4 o-clock it will cut out periodically, It always comes back within a second or 2 but it drops out pretty consistently. Maybe once every 5-10 seconds.
Here is a zip of the audio file ( won't let me upload wav files)

[TM Drop Outs.zip](https://github.com/TomWhitwell/TuringMachine/files/1866300/TM.Drop.Outs.zip)

jstamant, 2018-04-01:
If LED 2 is always off, the LED could be soldered on backwards. But don't remove it just yet. Try checking the voltage across that LED's leads when you suspect it's supposed to be lit. You should see ~2.2V when the LED is on. When the LED is supposed to be off, you should see 0V across the leads.

Or trying something else: measuring voltage from the + lead of the LED to ground, you'll see ~12V when it's supposed to be on, and 0V when it's supposed to be off. If you have it soldered backwards, you'll still see the same 12V/0V voltages.

As for your 2nd issue, how do you have your Turing Machine patched when you see this problem? Have you successfully calibrated your Turing Machine? And just for speculation, the Turing Machine doesn't produce notes, it produces random voltages. Your audio file sounds like you're clocking the TM at an audio frequency, and running the OUT jack right into your recording device or speaker, so I would expect it to behave as it sounds in your recording. Occasionally the TM might randomly clock in a set of all 0's, so there would be no change in output voltage i.e. no audio waveform to hear.

BlipSqueek, 2018-04-02:
Thank you for the help.
It appears that the only thing wrong then is the LED. It calibrates fine.
I tested the voltages. On the LED's ( + to -) I'm getting 1.69V on the working ones and nothing on the one that is out. Going to ground I get the expected 12V on all LED's. Did I put the LED in backwards? I triple checked and was sure they were all correct.

Closed 2018-04-02.

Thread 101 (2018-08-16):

No randomness

eliasbagley, 2018-08-16:
Hey guys!

I'm having some issues with the main randomness and length knob not affecting the behavior of the module at all. Hopefully you guys can point me to the part of the circuit that might explain the issues I'm having.

The issue is that no matter how I turn the main randomness knob (or CV input) or the length pot, it doesn't affect the output at all. I _can_ get values out of the output when I use the write switch, however. The write switch seems to be "sticky", in the sense that if all the lights are off, and I insert a single bit with the write switch and then release it back to the center off position, it will continue to insert bits from the left, as if I were holding the write switch up. No 0 bits ever get inserted again, until I manually write it in by flipping the write switch down. The same "sticky" behavior happens when I write a 0 - 0's fill in from the left as if I were holding the write switch down, even when I'm not. I don't think this is an actual issue with the switch though - I'm guessing that the part of the circuit that is doing the randomness and flipping part isn't working as it should, but I don't really understand that part of the schematic to debug it further.

I'm unable in any scenario to get bits to "wrap around" from the right to the left. Which part of the circuit controls this randomness and wrap around behavior? I'm guessing the issue is in there somewhere.

Here's what I think I know from the parts of the circuit that are behaving correctly -
1) Clock circuit works. The LED blinks and when I use the write switch, the top LEDS blink along with the clock.
2) Noise circuit works. I hear a strong white noise sound from the noise output, which is attenuated down to inaudible when I adjust the trimmer pot with a screwdriver.
3) Write switch works. Flipping it up writes a value into the left bit, although it's "sticky" - I don't think this is an issue with the switch though.
4) Scale pot works
4) DAC seems to work - the pitch of the output does change when I manually write bits with the write switch, and corresponds to the binary value indicated by the top LEDs.
5) Pulses LED blinks when there is activity on the top LEDS from manually writing bits
7) Shift register ICs seem to be working - when I write a 1, it does move along left to right, although in the "sticky" manner I described above.

Any ideas? I'm planning on poking around the circuit a bit more to try to rule out any broken traces. If that doesn't work, which components are likely at fault? I might order some replacement components just to rule that out.

I've already reflown all the solder joints, and they look pretty decent to my eye, verified that no IC pins are folded back on each other, swapped like ICs around to see if that changed anything, and verified that there's no shorts between +12, -12, and GND. Problem persists in all these cases.

I'm happy to post some high res photos of the boards or a video of the behavior, if that helps.
Thanks for your help!

Thonk-Steve, 2018-08-16:
I'm on holiday at the moment so can only provide brief feedback, have you
used a continuity checker on your multimeter to make sure that all the
mating pin headers between the two boards are connected properly and that
no pins are accidentally bridged? It sounds possibly like the back board is
working fine but the controls aren't getting to it.

Steve

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

Thonk-Steve, 2018-08-16:
Oh and when and where did you buy the PCBs? which revs are the front and
back boards?

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

eliasbagley, 2018-08-16:
Thanks for the quick response! I'll check the mating pins today. I bought PCBs from Thonk - I don't have the PCB in front of me right now but I believe it said Version 5 - August 2017.

Thonk-Steve, 2018-08-16:
ok let us know, the revision number will likely be different on each board

On Thu, Aug 16, 2018 at 5:35 PM, Elias Bagley <notifications@github.com>
wrote:

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

eliasbagley, 2018-08-31:
I did some basic tests by pulling out the comparator circuit's op amp and 4016 and wiring them up to a simple circuit. Seemed like the 4016 wasn't doing anything, so I ordered some replacements. I'll report back to let you guys know if this solved the issue.

eliasbagley, 2019-01-02:
I figured out my issue - I burnt out one of the traces on R16, which sends the noise control signal into the start of the shift register, so it wasn't getting any source of randomness. I fixed this with a simple jumper wire. It's working beautifully now :)

Closed 2019-01-02.

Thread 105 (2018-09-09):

Replacement Electrolytic Capacitors

Techsture, 2018-09-09:
OK, new to this whole DIY thing and soldering for the most part.  Build a Chord Organ and Radio Music before trying to tackle the Turing Machine MKII.

Well, I still appear to have gotten ahead of myself.  While removing the electrolytic capacitors from the packaging, I yanked one of the legs off of one of them.  Being new to this, I shoved it back in thinking, "yeah, this is fine, I'm a pro now!"

Cut to a couple hours or so later and I'm plugging in my TM2.  The lights blip on real fast, then nothing.  Try again, not even a blip.

I checked a few things utilizing my limited knowledge of a multimeter, and I think the issue is the capacitor (one of them acts differently from the other).  Of course, took me about 30m of doing random stuff before I remembered the capacitor kerfuffle.

Anyways, what can I get for a replacement?  I think they're these, but I just want to be sure:

http://www.oddwires.com/20pcs-10uf-35v-85c-panasonic-eca-1vm100-electrolytic-capacitor/

Thanks, I love Music Thing Modular!

TomWhitwell, 2018-09-09:
Hi, sorry to hear that. Those replacement caps look OK to me
Be careful when you get them to check how they’ll fit - sometimes caps are slightly bigger than you expect and you have to work out a bit of a kludge to fit them in - for example leaving a bit of extra length on the ‘legs’ so you can lie them flat against the board.
We specify extra compact ones for some kits to make it easier - so just check it all fits before you solder them in. But I’d definitely buy these because that retailer looks much more user friendly than Mouser.

Also, of course, check & double check the polarity of the electro caps.

There is always a risk with this kind of ‘magic smoke’ moment that something else will have been damaged in a short circuit, but fixing the cap definitely sounds like the place to start.
Good luck!

Techsture, 2018-09-12:
I just wanted to follow-up in case anyone in the future sees this.

The Panasonic 10uF 35V 85C caps DO work, I managed to get my Turing Machine MKII working!  👍 Just be aware that they are almost twice the height of the caps that come with the kit.  Leave a bit of room in the legs so you can tilt them slightly to the side so there's enough room to plug into the front board.

Thanks again @TomWhitwell for your help!

Closed 2018-09-09.

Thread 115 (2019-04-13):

Sharp spikes on cv changes

kimitobo, 2019-04-13:
Hi there,

Freshly soldered Turing Machine spikes all cv changes very sharply, effectively clicking the pitch out on every cv change clock. Especially on ascending pitches. Prior to this I fixed the same "reversed-scale-pot" (issue #87) successfully relsoldering R26 (to Pin2 on TL074) after which the spiking/clickig appeared. Triple checked that area of circuit, any chance problem being elsewhere? Scope image attached, I have also video, but should be pretty obvious from the pic.

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

Thonk-Steve, 2019-04-13:
What are you clocking the Turing with? Does changing the clock source
change that at all?

On Sat, Apr 13, 2019 at 12:13 PM Tuomo Tammenpää <notifications@github.com>
wrote:

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

kimitobo, 2019-04-13:
Tried few clocks, Echophon & Maths(EOC) and one external sequencer clock, pretty much same. After few different sequences, it's quite consistent that the peaks occure when the pitch is rising, decending cv does not have the peaks.

Thonk-Steve, 2019-04-13:
If you attenuate the input clock signal does it affect the amplitude of the
spike?

On Sat, 13 Apr 2019, 17:23 Tuomo Tammenpää, <notifications@github.com>
wrote:

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

kimitobo, 2019-04-13:
Yes! That did it! Bit of modular noob still, did not occur to me you can attenuate clock, well of course you can :) So clock down to about 1v with Maths did it. I guess I can add voltage divider resistor pair directly on the module to save my my Maths channel? Anyway, thank you so much for quick responses. Quality customer service :)

Thonk-Steve, 2019-04-13:
Ah well that at least gives you a workaround... BUT it does suggest you
maybe have a.short circuit somewhere between the clock and the main output
as this shouldn't be happening and you shouldn't need to have to do this.

On Sat, 13 Apr 2019, 18:21 Tuomo Tammenpää, <notifications@github.com>
wrote:

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

kimitobo, 2019-04-13:
Ok, I'll have a closer look following the schematic.

kimitobo, 2020-04-27:
Now year later had another look on the spike thing and realised that I have (I think) the random voltages doubled, so voltage change twice in every clock. Also noticed, the last four LEDs has low-brightness steady blink on the clock. Likely all related. The "second random" is louder and peaks through and also creates this not so random "ping-pong" with the first random.
https://photos.app.goo.gl/TkqWVvjpzXYSu4dB9

Could you point me to the part of schematic / board where should I have a look. Did few re-solders but more specific area tip would be great. Or am I seeing things, and all are as they should be :) Thanks!

TomWhitwell, 2020-04-27:
Maybe start at the clock input?
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

kimitobo, 2020-04-28:
Problem solved. I was puzzled with the exact four last leds (or actually first I guess: B1-4) even clock blink and followed to the buffer and and chips. One corner leg was not quite in. I was so eager to pop it out, fix and try it that I did not pay attention if it was the buffer or and chip and which corner, so apologies for bad debugging report. Leaving a corner leg floating in the air creates this bug that is almost a feature: double random with higher pitch clock beat :)

Anyway, thanks again for a swift response!

Closed 2020-04-28.

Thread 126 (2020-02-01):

Lock problem

mikisos, 2020-02-01:
Finished Turing Machine build. While trying to calibrate as stated in the video a problem occurs:

When the 1M trimmer is turned fully clockwise, the pattern locks on every position on the big knob. When trimmer is turned in any other position anti clockwise the pattern doesn’t lock at all, regardless of the big knob position. Gives a feeling that the trimmer scaling would be totally wrong or something.

Leds, noise and everything else seems to be working. Could you guide me towards a solution, please?

Pics attached. The extra jump wire from ferrite to elcap is because original lead was lost while desoldering an elcap which appeared to be too tall.

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

mikisos, 2020-02-04:
Hi again,
I’ve been going through the connections with the schematics. Should R22 connect to 1M trimmer? There is no connection so I may be having a cold joint there.

TomWhitwell, 2020-02-05:
From this schematic: https://musicthing.co.uk/collateral/TuringMachine_schematic.pdf there is no connection between R22 and the trimmer - but R32 should be connected.

Tom

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

mikisos, 2020-02-06:
 Hi,
sorry I was mistaken. What I was meaning to ask was that should there be a connection between R22 and 50K change pot because there is none.

I got another Turing to switch boards and thus be able to narrow the problem. My back pcb works well with another front board so the problem is definitely on my front panel.

Best,
Mikko

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

mikisos, 2020-02-06:
Hello again,
Sorry for the inconvenience. The connections seemed to be right after all. Just very difficult to calibrate -just a tad anti clockwise from the maximum trimmer position seemed to give the right result.

Thank you for help!
Best regards,
Mikko

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

Closed 2020-02-07.

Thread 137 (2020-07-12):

Calibration issue - bad resistor?

cptnal, 2020-07-12:
When calibrating there's a very abrupt shift from noise to tone, to the extent it's impossible to dial in a range where it isn't either all random or all static. I've been through all the joints and, whilst not pretty, they look sound and not shorted. I've also checked as far as I can that all the components are in the right place.

However, R7 on the jack board shows 88K on the meter, and it should be 470K. The banding looks correct, so the question is is the resistor bad, and could that explain my calibration difficulties?

Thonk-Steve, 2020-07-12:
The best thing to do is post a photo of how R7 looks, as you can't reliably
measure resistance in circuit as it may be in parallel with another
resistor.

Steve

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

cptnal, 2020-07-12:
Hello, Steve. Thanks for responding so quickly. Here are some detail pics of the R7 area.

Cheers,
Al
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

iamdamosuzuki, 2020-07-18:
Not sure if this helps at all @cptnal, but I also have 88 Ohms across R7

cptnal, 2020-07-18:
Thanks, iamdamosuzuki (nice) but I don't think it does. What would be useful to know is whether a functional unit measures the same value across R7 when it's in circuit. Then we'd know whether that was normal or if it really is something to go on.

cptnal, 2020-07-21:
Update if anyone's still out there. Reflowed the pins on the main knob, which looked like they could do with more solder. Now I have no tone and no noise, only bleed from the clock signal.

TomWhitwell, 2020-07-21:
Do you have no noise from the noise output? What do you mean by ‘tone’?

cptnal, 2020-07-21:
Hi, Tom. Thanks for responding.

There's no sound from the noise output and I don't hear noise-transitioning-to-steady-tone at the main output when turning the trimmer. I was hearing these on my first attempt at calibrating, but after reflowing those joints they've disappeared.

Cheers,
Al

TomWhitwell, 2020-07-21:
R7 is part of the clock input so very unlikely to be a factor here. How frustrating. When you say ‘bleed from the clock’ - was that at audio rate?

cptnal, 2020-07-21:
Yes, I'm clocking it at audio rate per the calibration video. On reflection I think the bleed was from the muted channels on my mixer - there's nothing from the TM.

cptnal, 2020-07-22:
Update: Reseated a chip and now I have noise, which fades to silence as I turn the trimmer CCW. Still nothing at the CV output though. Also, the big knob appears to have no effect on anything.

TomWhitwell, 2020-07-22:
Do you get lights moving across the top LEDs when the clock is at sequencer rates and the main knob is at 12 o'clock?

cptnal, 2020-07-22:
Yes, I do. But the CV out doesn't appear to affect the pitch of the module it's plugged into, other than a slight wobble in time with the clock.

TomWhitwell, 2020-07-22:
OK, so the problem could be on the output: assuming you've turned the scale knob to 5 o'clock, check around there for any shorts or missing connections

cptnal, 2020-07-22:
All looks good down there I'm afraid. However, I've measured rather than listened and there's actually something coming out of the output. Around ten volts, and it appears to fluctuate +/- a tenth of a volt in time with the clock.

TomWhitwell, 2020-07-22:
If the LEDs are good but no CV output, then the problem is likely either the DAC0800 or the TL074 - check connections, look for shorts and chip orientation.

cptnal, 2020-07-22:
Looks OK, as far as I can tell...
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

cptnal, 2020-08-02:
Refusing to let this one go (the alternative is throwing £100 in the bin) so I tested continuity between the DAC0800 and TL074 legs, and their solder joints on the board - all beeping as they should.

I thought I'd test continuity between the leg of the output jack and the pins of those chips. Whether that tells us anything useful I don't know, but I thought I'd ask whether it's as expected. The yellow rings show continuity with the output.
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

cptnal, 2020-08-13:
Hello, folks. Is there any hope for this unit? Or is it a write-off?

TomWhitwell, 2020-08-13:
@cptnal those are GND points - were you testing the outside leg of the output jack - the one visible? If so, that's normal, because that's the ground pin.
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

TomWhitwell, 2020-08-13:
So at the moment:
Noise working?
LEDs moving across when clocked at sequencer rates?
CV Output gives +10v, fluctuating with clock?
Does the output go up and down when you turn the little scale pot?

cptnal, 2020-08-13:
Yes to the first two questions.

The CV output follows the scale knob - 0V CCW, 1V CW, 5V at noon.

TomWhitwell, 2020-08-13:
OK, so the problem is probably in this space: Which is pretty much the area I pasted above.

Pragmatically, I'd probably start by simply replacing the DAC0800 and the TL074 because that's quick and easy to do once you've sourced the parts. I don't know where in the world you are, if you're in the UK I'd normally recommend https://www.bitsbox.co.uk/ but they're on holiday.

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

cptnal, 2020-08-13:
Many thanks, Tom. I'll spend some time on that at the weekend.

cptnal, 2020-08-29:
Hello, Tom. New chips sorted the output problem, thanks for that. That leaves the calibration issue, but I've discovered that by overriding the big knob with a CV input I can make the until behave normally. The joints on the three resistors involved, and the knob itself look OK. So I'm wondering whether it's a problem getting the +12V or -12V to the knob. Can you give me a clue how I might trouble shoot that? My first thought was to check the legs with a multimeter, but hard to do with the module assembled.

cptnal, 2020-09-01:
Update: Reflowed the joints on those resistors and the big pot anyway, and I've now been able to calibrate properly and the module's working perfectly. Thanks, all.

Closed 2020-09-01.

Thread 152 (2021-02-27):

Working but impossible to calibrate and weird pulse and CV OUT (PCB & Osc pictures)

GrosBob, 2021-02-27:
Hi,

I'm facing two problems that occurred independently:

**1) right after building the module I couldn't calibrate it at all**. I did the following checks:
- Noise out OK
- Incoming pulse LFO is triggering the clock LED as expexted
- The noise trimmer seems to work as fully CW i can hear a kind of crushed noise that turns to sound as a white noise at 12 o'clock to end up fully CCW with nothing hearable, like a HP sweep from CW to CCW.
- Sequencer is running. I can add and remove bits using the switch. Pulse LED blinks on ON bits
- When the big knob is fully CW, the sequence is locked for hours. At 12, events start to be added to the sequence, that can be locked back the big knob is **very quickly** set back to fully CW, otherwise all bits are set to ON and CV to max.
- CV OUT is OK, at least its value change overtime
All this seem to be directly related to calibration issues if I understood well.
What is the frequency range of pulse wave I should feed as a clock to successfully calibrate the TM?

**2) today the TM started to behave strangely:**
- Pulse OUT triggers "normally" most of my modules (MI Plaits, DIY Befaco Rampage, DIY ADDAC T-networks), but I use TM to trigger all the 4 Proks (independently), a double trigger happens. The first on the ON bit (pulse LED On) and a second trigger occurs at the next bit, the next one only. I found out with a very basic oscilloscope that at the ON bit the trig signal was OK, but on the next bit there is a negative "trig" that manage to trigger the Proks. This negative trig only appears at n+1 bit (if n is the right trig.
See the pict below:
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

- Then I went back to control trig and CV (for Pitch) of Plaits and realise that CV out was also behaving differently. Instead of playing stable pitched notes, there was like a kind of portamento effect in between every ON events, but not a real portamento. Below two picts of the CV signal (one in DC mode, the other in AC). And here also there is a negative peak appearing after the ON bit. I suppose this neg peak is the cause of this protamento like effect.
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

I'm wondering if those two problems are linked. The appeared not at the same time. The double trig/portamento happen this morning when I powered the case.
Any ideas will be more than apreciated.

Here are the 4 pictures of the boards before someone ask me to post them.

Thanks

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

GrosBob, 2021-03-10:
Hello,

I finally manage to calibrate the locking of the TM. Every thing is working great for now.
Except the problem I mentionned concerning the  inverted'"gate signal coming out on the bit following a normal gate.
I didn't noticed it fist as the TM was triggering normally all the modules I have that can accept a gate signal.
I only notice this problem when triggering the Proks Drum modules (all the four). SO I'm wondering if the problem come from the TM itself or from the Proks that respond to a negative gate.
Could you tell me if it is normal to have this negative trig at bite n+1?. And if this comes form a problem of the TM, where should I start to fix this.
Thanks in advance, I begin to feel desperate...

TomWhitwell, 2021-03-10:
Hi,
I'm glad you have it working.

I'm afraid I don't really understand what you mean by a negative gate.

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

In this image you have the AC coupling on your oscilloscope

The negative pulse on your scope is simply the AC-coupled signal returning to zero. AC coupling shows CHANGE, not actual values. It's negative because it's going from n volts to zero volts, so is showing -n volts of CHANGE.

On a DC couple scope it would simply fall from n to zero.

You shouldn't get a double trigger - that would normally require the voltage to return to zero, then rise again above the threshold (likely 2-4 volts)

Tom

jstenroos, 2021-03-10:
Hi,

What happens there is not a negative gate, but a very short ghost trigger on the n+1 position.

A picture tells it better:

It’s actually a design problem, to overcome that it would require a very slight delay on the AND operation to let the up and downward edges to settle.
Most modules do not react to such short triggers, but some do, on my system MakeNoise Maths trigger input was the only one.

I solved the problem by adding small caps as low pass filters on the pulse outputs, also to the pulses extension module.

Best,
Jouni

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

GrosBob, 2021-03-10:
Thanks for your replies..
@Tom, I definitely agree and understand. The strange think is that only the Proks are triggered when the Pulse Led lit and once again on the next step even when it's off. This happens also when using the Pulse extension outs.
The explanation of Jouni makes sense to me. Could you tell me what cap value and exactly where you put them, especially on the Pulse extension. I would really appreciate.
Thanks in advance
Eric

GrosBob, 2021-03-10:
@ Jouni: You saved my life!!!
I just tried a 100nF directly from a patch cable and ...miracle!!
I successfully went down to 1nF. Time to solder...

Anyway, thank very much for your very constructive feedback.
All the best

Eric

Closed 2021-03-10.

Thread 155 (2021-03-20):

No Random, reverts to same CV out

nickkjordan, 2021-03-20:
I'm getting a behavior similar to in #145 and #122. I've tried the calibration, but I'm getting only sporadic glitches and not any more or less adjusting the main knob. I am getting noise output with level proportional to the trimmer.

CV out can be modified with the switch, but it reverts to the same behavior which is an ascending then descending line, with pulses in the middle. I'm not really sure how to debug from here, but I've resoldered everything on the control board. I can attach a video of the behavior if it seems necessary.

nickkjordan, 2021-03-21:
Hopefully this helps someone out with similar issues and points them in the right direction, but I'm feeling a bit of :shame:

Because it seemed like everything was working besides the loop control knob (random vs locked), I took a look at the schematics and found it pretty much feeds directly into the TL072. I was going to switch it out, assuming I'd accidentally fried it, but realized it wasn't even there. Placed it, and it's working perfectly now.

TomWhitwell, 2021-03-21:
Mate, we’ve all done it

vfilby, 2021-04-22:
Hi Nick,

Just wanted to let you know that this was very helpful to me!  Had exactly the same behavior and while my IC was in the socket I didn't fully solder in the pins in the socket.  I had just tacked the two corners of all the sockets then did the rest of the pins... and missed the last socket.  Once I actually soldered the pins everything works perfectly.

Thanks!

Closed 2021-03-21.

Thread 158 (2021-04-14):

Voltages expander

martbarras, 2021-04-14:
Hi

I’ve just finished the build but the 4th, 6th and 8th leds on the respective sliders don’t light up when the unit is on, these sliders also don’t seem to have any effect either, I’ve checked the solder joints and they all look good so I’m not sure what’s going on, or if there is something I’ve stupidly done.
The unit seems to function ok apart from this

any help/ pointers greatly appreciated

Cheers

martin

TomWhitwell, 2021-04-15:
Hi, sorry to hear that.
The most likely cause is a bad/missing solder  connection to the ribbon connector or the fader. Or potentially a short to ground at the LEDs?
You could also test the unit by connecting to the ‘pulses’ output on the Turing - to see if the LEDs flash then. if they do, the fault is in the main module, not the expander.

martbarras, 2021-04-16:
Thank you Tom

I appreciate you taking the time to reply, I’ll try these suggestions today and hopefully I’ll be able to fix the issue 🤞

Cheers

Martin

martbarras, 2021-04-16:
I’ve tried connecting it to the pulses output and only some of the leds flash, not all of them.
 I’ve also reflowed the solder on all the connections and it now seems to have all the leds light up if all the sliders are all over to the right, 5, 6 and 8 however seem to be at a lower brightness and when slid back to the left dim and turn off, the other leds don’t seem to exhibit the same properties.

Is it worth me trying to desolate the sliders and take a look under, the solder points below these all were trimmed carefully and haven’t caused any to be higher up than the rest.

TomWhitwell, 2021-04-16:
That sounds very odd - the fader positions should have no impact on the led brightness - so that sounds like a short or a bad connection. I wouldn’t advise desoldering the faders unless it’s an absolute last option, as it will be tricky to do, but if you’re confident about everything else... you could try removing the chip, so see if that has any effect on the LEDs (the outputs won’t work while it’s out)

martbarras, 2021-04-16:
Thanks Tom

So tried taking the chip out and led 3,4,6 and 8 don’t light up when they are across on the left.

If I push all these leds to the right they still don’t light up and require 2 of the other ‘working’ leds to be pushed over to the right, before they too will all light up and flash, albeit at a lower britness than the functioning ones.

martbarras, 2021-04-16:
After removing the chip and the results above, I decided on a whim to de-solder the power.
Once I had removed all of the solder, I then set about soldering the connector again and low and behold its fixed the issue.

I’m not new to soldering (I used to do as part of my job) and I’ve been checking my work as I go with a 10x mag eye glass. I can’t say I can see any physical difference with the joints than the way they looked before, but just by removing and re applying has solved it.....phew :)

Exactly as you said Tom, it must have been a bad connection.

Thank you for your time and help, your a legend !
Cheers
Martin

Closed 2021-04-16.

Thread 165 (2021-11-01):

Turing Machine Mk2 no pitch CV out, single voltage level

tim-gregory-pt, 2021-11-01:
I assembled a full kit bought from Thonk. I also have Volts and Pulses expanders (pre-built).
The TM mostly seems to work - I get flashing lights from the TM and the expanders, I get noise out at a fairly high volume, and I can use the trim-pot to get it to lock/latch using the calibration procedure video (but it needs to be 90-95% CCW to stabilise on the latching). Expanders work fine, and I'm getting some different notes out of the Volts.

Problem is that I don't get any variation in the tones output from the TM itself, it's always just a single tone.
The pitch is influenced by the scale trimmer, and I can lower or raise the pitch, but there is no variability.

Things I tried to fix it - reflowed everything twice, switched the 50k pot, switched the DAC, switched the 072 chip, switched the 4015's.

Any ideas where I could trouble-shoot? I feel like it's so close to working, I just need to work out what is preventing it from sending out a stream of different pitches instead of a single steady voltage.

TomWhitwell, 2021-11-01:
Hi Tim, sorry to hear that.
Just checking - when you say tone, you mean pitch when the voltage from the CV output is connected to an oscillator? (Had to check)
So if you have happy flashing LEDs but no CV output, the problem is somewhere here:
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
It's the TL074 that powers the output voltage, so any problem / missing joint there, or if the TL431 voltage reference had been mistaken with another transistor-shaped component that could be a problem. Sometimes it's as simple as a missing solder joint on the output socket, or a short to ground somewhere around there.

tim-gregory-pt, 2021-11-01:
Hi Tom, thanks for responding here, and thanks for the detail on where to look. Yes, I am not getting pitch CV out, only a single pitch, which responds to the scale pot. I'll take a look more closely in the morning. If you're interested, here is a short video demonstrating what I'm getting https://youtu.be/qJ020EzP2i8

TomWhitwell, 2021-11-01:
Yes the video reinforces what I suggested above. Although a voltage is getting to the pot and out to the socket so the issue in the TL074 or DAC or supporting components

tim-gregory-pt, 2021-11-02:
I focussed on the area indicated and checked the TL431, tried another DAC, reflowed everything, checked all the resister values and looked for shorts but I'm still getting the same symptoms. Except now I seem to have lost 1 & 7 on my pulses!
I don't have any spare TL074 at the moment so I've ordered a few and I'll switch that out in a few days and see if it fixes the issue.

tim-gregory-pt, 2021-11-02:
Success! - I scrounged for a spare TL074 in my unbuilt kits and switched only this, and now everything is working ok, including the pulses lights that I lost.

Closed 2021-11-02.

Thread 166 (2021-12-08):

Workaround for lack of clock reset functionality?

othmar52, 2021-12-08:
Recently I bought and built TM MKII and pulses DIY kits and i like it so much!
@TomWhitWell Thank you for those great modules!!!
I am going to get the volts expander kit soon.

There is only one tiny thing that's a bit annoying and i am wondering how to "solve" this.
In my personal use i often make music with a bunch of other people with all kinds of synchronisable music equipment. we are all synced via midi-clock/cv-clock.
every now and then its necessary to restart the master clock in case one of the dozens involved devices has lost a clock tick or gets out of sync for whatever reason.

As the Turing Machine has no "clock reset" (start locked sequence from step 1) a clock restart results in a time shifted loop which is very disappointing for all involved musicians - especially for me because i am the one who destroys the flow/mood of the track we're performing by having my stuff not in perfect sync with the rest of the "band".
I have to admit that this is a very exotic edge case but i am trying to find a solution/workaround for this.

The first thought i had was to create an extension module with a single pushbutton. pressing this button generates a single clock pulse which gets added to the existing clock input. Theoretically it should be possible to feed manually triggered clock pulses until everything is in sync again, right? maybe its tricky to trigger it between master clock pulses or maybe it's better to hold the push button to prevent the master clock input to go to 0V again.
Ugly solution but at least a possible way to be able to mess around with to get in sync again...

Pretty sure this circuit is no rocket science but unfortunately my knowhow about electronics is not that good :/

Can i take the 5 Volts from the eurorack power bus and feed it directly (parallel to the main clock) into the clock input via a pushbutton?
Or will i destroy the TM with that approach?
Do i need a resistor?
Would this also be possible with the +12V potential of the power bus (to support other power supplies without 5V)?
Or is this not the right place for such a question?

Or do you have any other idea how to get a locked sequence in sync again after a master clock start/stop?

Thonk-Steve, 2021-12-08:
The short answer is you can't reset the 'sequence' in the Turing Machine as
it doesn't remotely resemble a sequencer under the hood.

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

othmar52, 2021-12-12:
@Thonk-Steve thanks for your answer!
In the meantime i have created an expander module for the TuringMachine:
https://github.com/othmar52/eurorack-gatenudger
currently only on the breadboard but everything is working like expected so now i am able to move the locked "sequence" left and right by adding/supressing single gate pulses via 2 pushbuttons...

TomWhitwell, 2021-12-12:
Amazing @othmar52 - keep in touch with progress

othmar52, 2022-02-06:
> Amazing @othmar52 - keep in touch with progress

@TomWhitwell I already have created a few eurorack modules, but this is the first time it feels like a **real** module
With very little knowledge of electronics & stuff but with a lot of patience and passion i am proud to present [homogate](https://github.com/othmar52/eurorack-homogate)
It's finished and everything works exactly like it was intended to be.
Maybe i am going to create a short video which demonstrates the "nudge left/right" for TM's locked sequence soon...

Closed 2021-12-12.

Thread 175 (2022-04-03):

Turing machine MK2 half working

MattCufre, 2022-04-03:
Hi,

I put together a turing machine over the weekend and it's...half working? I had it working for long enough to calibrate it, so I know it does work, but I moved it to add in the pulses expander and since I've put it back (with or without pulses) it's now not working as expected. The first four leds run as expected, but the second 4 leds are either statically lit, or off. If I use the write switch to remove bits and lock the sequence, it will run for the first 4 leds, but then stop.

I found that if I put pressure on the power socket (not something I meant to do) that it will then run as expected. Basically I wondered if I'd plugged the power in correctly when it first wasn't working properly, pushed a little harder than maybe I should, it started working, I released, back to half working.

I was wondering if there was a way of narrowing down this to either a chip, my soldering (reasonably experienced with DIY builds, have 10 other builds working as expected), maybe burning a trace (can't see anything obvious), or if it's something I've not thought of. I can post some pictures later if needed. I've also run through the basic troubleshooting steps of checking solder joints, double checking resistor values against build documents and everything seems to be correct.

Thanks in advance for any help!

Thonk-Steve, 2022-04-05:
Hi,

It sounds like either you have a bad power cable or you could do with
giving the power socket a re-solder just to make sure there are no bad
joints.
That's what i'd try next, if it doesn't work after that test for shorts on
power header with a digital multimeter -
https://www.youtube.com/watch?v=qS0SoIiiQCo

If the multimeter test is ok send us photos of both sides of both PCBs.

Steve
Thonk

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

MattCufre, 2022-04-07:
Thanks for the reply, got it working.

I had been looking at the chips (as I thought that was the easiest thing to change), and so I swapped a couple over (the ones that there are 2 of) and it suddenly worked without question. I wonder if maybe something wasn't quite seated right in the socket.

Even though I got it working by guessing at a potential problem, I did resolder the power socket anyway as that seemed a really sensible suggestion.

Closed 2022-04-07.

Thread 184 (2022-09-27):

4016 question

holmesrichards, 2022-09-27:
Not so much an issue as a couple questions about the schematic. Not sure I'm understanding things correctly but a couple things seem odd.

IC7B (TL072) is wired as a comparator, powered by ±12 V, whose output goes through a 100k resistor to two control pins on the 4016. Doesn't that mean there are voltages of about -10.5 V being sent to the control pins? I understood those input voltages were supposed to be above -0.5 V.

Also, what is the purpose of the series 100k resistor?

Thanks, by the way, for this great design!

holmesrichards, 2022-09-28:
On closer examination of the CD4016 datasheet I see it has protection resistors, which will clamp the voltage to no more than -0.5 V provided there is a series resistor to drop the voltage, so I guess it's all good, never mind!

Closed 2022-09-28.

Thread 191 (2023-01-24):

Pulse don’t work

LegendaryTeacherLiu, 2023-01-24:
Hi！
I just finished the Turing machine.But the PULSE does not work, and the led is not light. I made a lot of efforts and replace all the chips，Can't fix it.PULSE no signal.
I measured the pin of the chip with an oscilloscope.  The output voltage of CD4015BE  pin 5 is lower than that of other output pins.

This is pin 5 in the schematic diagram，i think it triggered the pulse1.and the Pulse1 finally forms the PULSE.
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

here is  the picture of the oscilloscope for pin 5.
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

here is  the picture of the oscilloscope for the other pin
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
It is obvious that the output voltage of pin 5 is lower than that of other pins. i think it triggered the pulse1. and the Pulse1 finally forms the PULSE.
This is pin  pulse1 in the schematic diagram
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
I measured pin 3 of the chip 4081 with an oscilloscope, and there was no signal output
I replaced all of  the chip, but it couldn't solve the problem The same problem still exists.
 I'm confused，How to solve this problem.
thks！

LegendaryTeacherLiu, 2023-01-26:
The problem has been solved. It is a 2.2k resistance short circuit of LED and GND. It has been solved. Now it can work perfectly.

LegendaryTeacherLiu, 2023-01-26:
thk

Closed 2023-01-26.

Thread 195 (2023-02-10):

No Noise nor randomness

MFallise, 2023-02-10:
Good day,

First tests on my newly built Turing looked fine until I discovered that actually, randomness was missing. After double checking soldering, re-calibrated and some additional tests, here is my status:
* Sequencing is fine (length selection behaves correctly, clock ok)
* Scale => OK
* CV OUT => OK
* PULSE => OK
* Lock trimmer => looping Ok (see below)
But...
* Nothing comes out of Noise OUT
* Randomness (12 o'clock on trimmer) keeps looping on the same sequence without any variation
So...
I've could create a "randomness" by patching a LFO in the CV IN, then, wiggling the trimmer around the 12o'clock creates some "fake" randomness (actually following the LFO) and can lock (full CW ) on a sequence. But that's not what the baby is made for, right...
This looks like close to this issue: https://github.com/TomWhitwell/TuringMachine/issues/97
Based on this thread, I've checked the schematics and this really looks like local to the noise generator circuit. As I see, there could be only 2 causes for my problem: either the 2N3904 or the TL074... IMO, assuming that I get a correct CV OUT which also uses the TL, it seems most unlikely that it's damaged (am I correct ?). So, all my suspicions focuses on the 3904...
Could you suggest a workaround or a way to verify my assertion ?

Cheers,

Mike

TomWhitwell, 2023-02-10:
Hi, sorry to hear that, no noise will mean no randomness so that sounds right

MFallise, 2023-02-10:
Thank you Tom for this quick reply. Do you think of any advice to troubleshoot/ locate the issue ?

MFallise, 2023-02-17:
Hi Tom, ordered a new 3904, and happy to say that everything works like a charm since then. Meanwhile I ordered the Voltages expansion and, boy, this is some nice piece of hardware!
So this issue was relying on a overcooked transistor and is now closed for me. A hint for amateur electricians like me: Be very careful when soldering transistors, they are very sensitive to high temperatures.

Cheers,

Mike

Closed 2023-02-17.

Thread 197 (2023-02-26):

All lights on at power-up, output inverted?

mightysmooth, 2023-02-26:
I just completed my first TM mkII but it doesn't work as expected. When I power up all the 8 lights at the top of the module stay on even with no clock present. I have connected up to the pulse output of an oscillator (as per the calibration video) and I get some random output but the signal seems inverted, with the range pot fully CW the module outputs a constant ~10V which then drops towards zero on the steps. Locking CW causes the output to become intermittent, I seem to get some loop but it changes every few seconds and eventually goes back to a steady ~10V output. I have a Volts expander and the output of that exhibits the same behaviour (**EDIT:** this is not actually true, I have now confirmed the Volts output works as expected). I have tried disconnecting the Volts expander but it makes no difference. All ICs have been reseated and I have checked all my solder joints (the soldering probably isn't perfect!). Images of the boards attached.
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

mightysmooth, 2023-02-26:
A few other things I've checked:
- Noise output seems fine ~8V peak-to-peak
- Output voltage changes from 0 to ~+10V with the range pot as expected
- I've tried a few different clock sources/oscs and also tried changing the pulse width but there is no noticable effect
- With the top board disconnected the shift registers all output ~+12V on every output pin

TomWhitwell, 2023-02-26:
Sorry to hear you're having trouble.

**When I power up all the 8 lights at the top of the module stay on even with no clock present.**
This is normal behaviour

**I have connected up to the pulse output of an oscillator (as per the calibration video) and I get some random output but the signal seems inverted, with the range pot fully CW the module outputs a constant ~10V which then drops towards zero on the steps.**
Do you mean when LEDs are off, you get max voltage out? That's very much not normal behaviour

 **I have checked all my solder joints (the soldering probably isn't perfect!). Images of the boards attached.**
Soldering looks good to me

**With the top board disconnected the shift registers all output ~+12V on every output pin**
That might not be odd if there is lots of noise going through the shift regs it could appear that they are all on all the time

mightysmooth, 2023-02-27:
Now that I have done some more testing I think the problem may lie with the DA conversion somewhere. Taking account of the fact I haven't been able to calibrate yet, the behaviour of the LEDs seems to align pretty well with what I'd expect in terms of randomness and locking with the main knob positions. Its just that the output voltage doesn't seem to reflect what I'm seeing with the LEDs! It was too difficult to spot this when I was using the oscillator to clock it for the calibration procedure.
I presume the input to the DAC must be ok as the LEDs are reflecting the right sequence but I don't have suitable equipment to check this and confirm. Am I on the right track here do you think?

mightysmooth, 2023-03-01:
I've checked the circuit with an oscilloscope and it looks like the DAC is getting all the right input. I have checked the DAC output and it is always negative, is this expected? The symptoms sound very similar to those reported in issue #178 but I don't know if that was ever resolved? Voltage at pin 14 of the DAC is 0V when the DAC is in place but changes to around 2.5V with the DAC removed. Is this indicative of a broken DAC do you think? If so, do you have any suggestions for a replacement as I'm struggling to find another DAC0800LCN in stock online.

TomWhitwell, 2023-03-02:
Yes, that all makes sense. You can check the TL074 on the front board - Pins 1,2,3 are the circuit that scales the DAC output - if the pin 2 or pin 3 connections is bad you might have these symptoms
If it is the dac - in the UK, Bitsbox have DAC0800 in stock, otherwise try support@thonk.co.uk ?

mightysmooth, 2023-03-12:
Problem solved, I focussed my attention on the circuit around the TLO74 and there was a build error. I had managed to swap the 5.1K and 51K resistors for R26 and R5, having corrected that mistake the module now works flawlessly. Many thanks for the assistance Tom

Closed 2023-03-12.

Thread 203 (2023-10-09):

Unable to calibrate. Steady tone until 12 o clock

kengc, 2023-10-09:
This is a full thonk kit (plastic bag version).

1) I have my TM in calibration 'mode' (following the settings from the TM calibration video)...

As mentioned i am unable to calibrate my TM. Turning the calibration trim pot does nothing (sound doesn't change).
Turning the random knob from 5 o'clock up to 12 o' clock and the calibration sound cuts out.

Here a video showing this behaviour (will need to turn up your sound for this video to hear the calibration tone)

[https://youtube.com/shorts/V4v92kzYj6o?feature=share](url)

2) NOT in calibration mode. Just sending a clock (100 bpm) to the TM and have the random knob parked at 12 o' clock. I click down on the switch to remove some bits and we can see that the TM doesn't really generate randomness and, in fact, toward the end of the following video all LEDs eventually are lit and no changes happen after this.

[https://youtube.com/shorts/51hkEWINENg?feature=share](url)

Some trouble shooting steps i have taken:
1) swapped the two 4015 chips places
2) inspect soldering work and touched up as precaution
3) doubled checked all component position/placements against build doc
4) google search, including this help git for TM, and not seeing anything so far that helps my situation

I feel like one of the shift reg chips might be buggered or perhaps the big random knob is wonky? Any suggestions would be greatly appreciated.

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

Thonk-Steve, 2023-10-10:
Hi Kevin,

Thanks for the info, despite the calibration not seeming to work, is the large knob having any effect on the output when operating at 'normal' tempo like in your second video?

Also is the white noise output working and delivering a loud signal?

Steve

OzzyMantis, 2023-12-03:
I am also having the almost exact problem as you. Has there been any resolution or any advice in troubleshooting the issues?

kengc, 2023-12-04:
Unfortunately my unit is still doing this

kengc, 2023-12-27:
Ok I solved my problem. Another clue i had forgotten about was my module was sending some pulses out of the white noise jack. Not the same pulses as the dedicated pulses jack, but similar. Anyway after following all of the white noise traces on the board i suspected something had to be up with the Link 1 header.

Upon very close inspection with a bright LED light and my magnify glasses i could see a shiny reflection that appeared to go from pin 1 (white noise) to pin 2 (step 16) check photo with yellow indication line:

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

Some might not be aware but one can gently lift the plastic shroud up off the circuit board for these headers to better inspect the pins (i used the smallest flat head screwdriver from my eye glasses kit, it's quite small), sure enough a loose piece of solder was there connecting the aforementioned pins. After removing the solder, and gently pushing the plastic shroud back down, the module works exactly how it should. At 12o'clock it's randomizing like a champ. No more pulses out of white noise and i could finally calibrate it properly.

Closed 2023-12-27.

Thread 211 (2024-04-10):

Sequence either gets filled completely (anticlockwise) or dies out (clockwise)

mrmitchley, 2024-04-10:
Built a TM and a vactrol mix, and it was functional (calibrated, correct outputs, responded to CV on all inputs), but had the following issues:

1. Clock LED was not working
2. Accidentally chose super long 2x6 male pins, so the two boards were in contact, but were not mated nicely - I also didn't have m3 nuts, but the module was working, so..

I built a Pulses, so took the opportunity to reflow the resistor closest to the LED. On restoring it to the case, I found the following strange behaviour

1. When the main knob is CCW, the sequence is always on, then off (eg 8 on, 8 off). Introducing any randomness or flipping the write switch in either direction introduces a change, but within 2 or 3 cycles it settles back to on, then off.
2. When the main knob is clockwise, the sequence is always off. Any randomness introduced or flipping of the write switch quickly dies out within three or four cycles, always dying out in a similar sequence (eg 8 on, then 5 on, then 3 on, then 2 on, then nothing, always clumped together)
3. The clock LED still doesn't work, but the clock input does advance it correctly
4. The boards are now somewhat secured with m3 nuts on the spacers, but now it doesn't work, so...

mrmitchley, 2024-04-11:
I've also tried swapping all the paired chips, no change in behaviour.

Noise output is good, CV and pulse output are consistent with the LED pattern, module is fully random when at 12, and sequence lengths are correct.

mrmitchley, 2024-04-12:
I took it out and jiggled it all, and the behaviour is now slightly better (seems to be dropping a bit at position 7/8) so I think bad connection is likely the culprit here. I may need to replace the pin headers and reflow the chip sockets.

For the doubled sequence lengths of the counter-clockwise position, is there any difference between how the first half of the sequence and the second half are handled? The second half always seems to be zeroed off.

mrmitchley, 2024-04-17:
OK, the issue with the CW behavior is definitely in part a loose connection between the two boards, I've solved it by making sure they are very tightly pressed together, and I swapped the shift registers

The issue with the CCW behavior is still there, so perhaps its one shift register thats a little buggy (bad connection? issue with the board connection exacerbated by the back and forth? unsure).

I'm going to go ahead and mark this as closed, with the warning for future travelers: make sure your male headers are all the right size.

Closed 2024-04-17.

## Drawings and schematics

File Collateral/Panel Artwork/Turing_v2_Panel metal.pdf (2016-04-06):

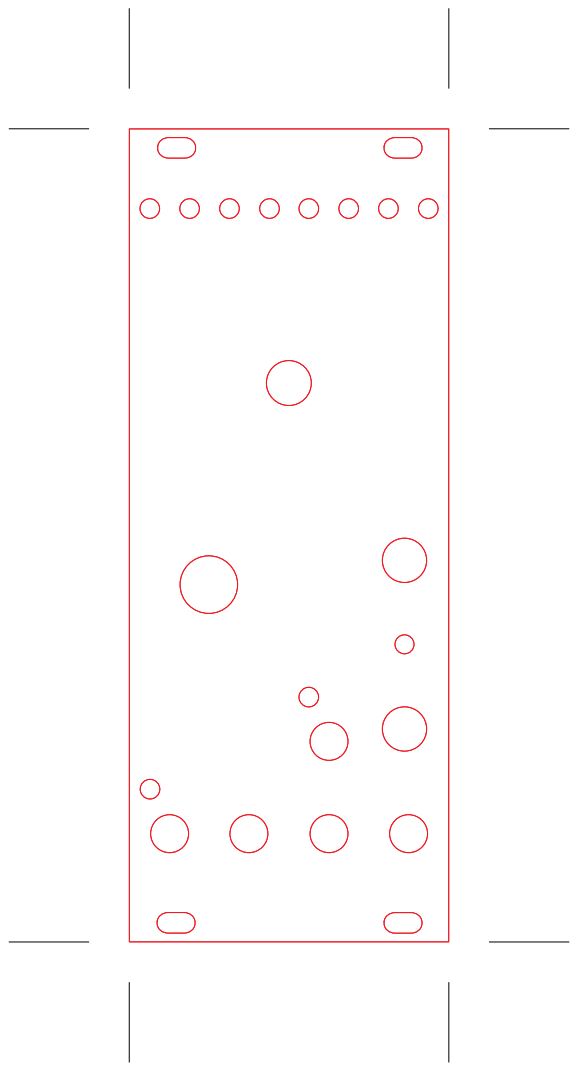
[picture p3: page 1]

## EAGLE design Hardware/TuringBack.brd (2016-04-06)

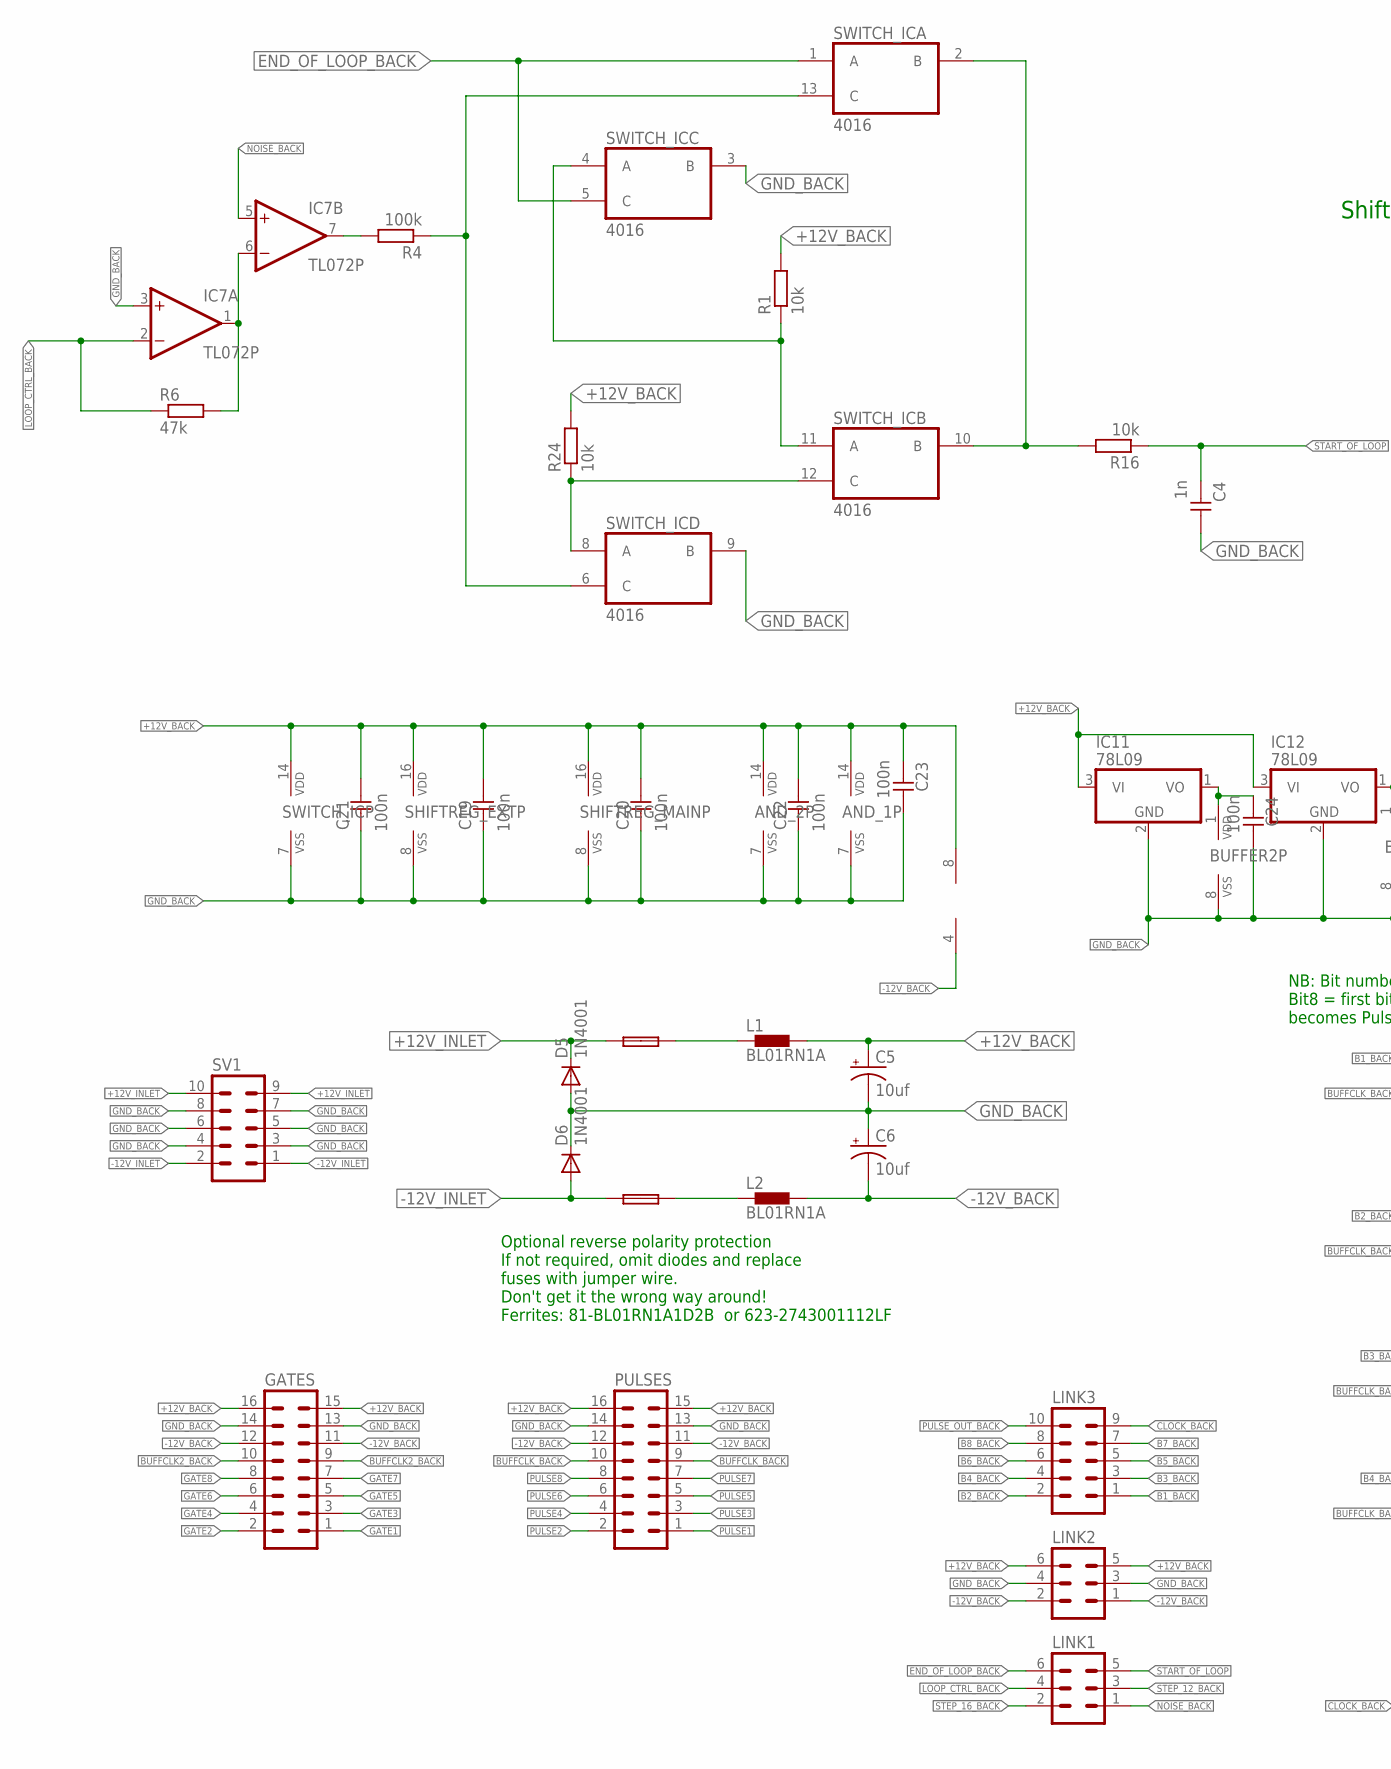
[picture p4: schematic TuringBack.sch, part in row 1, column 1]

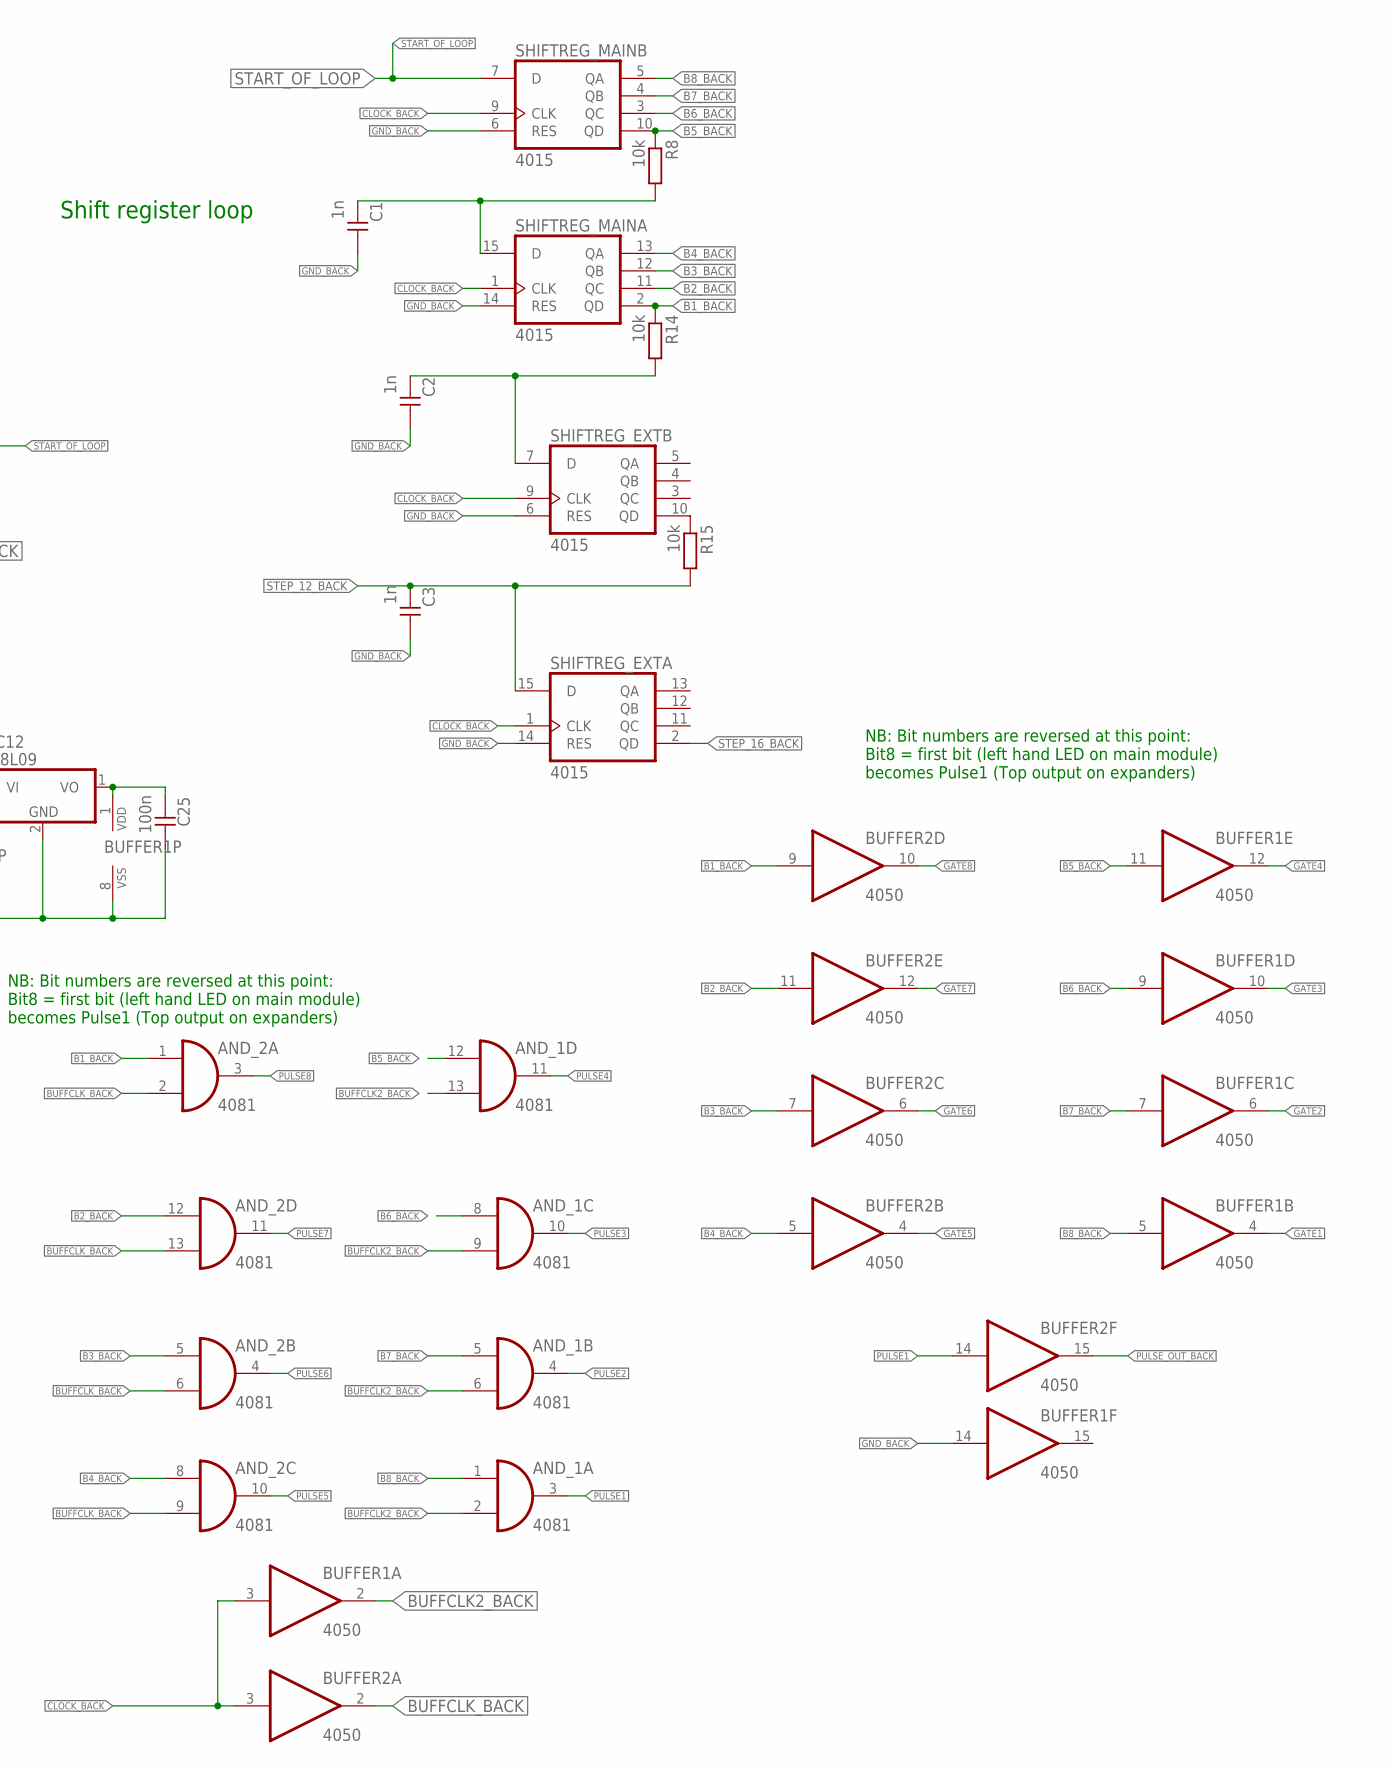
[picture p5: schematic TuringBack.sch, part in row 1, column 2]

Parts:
+FUSE: +FUSE; C050H075X075
-FUSE: -FUSE; C050H075X075
AND_1, AND_2: 4081; DIL14
BUFFER1, BUFFER2: 4050; DIL16
C1, C2, C3, C4: 1n; C050-024X044
C5, C6: 10uf; CPOL-RADIAL-10UF-25V
C19, C20, C21, C22, C23, C24, C25: 100n; C050-024X044
D5, D6: 1N4001; DO41-10
GATES: MA08-2
IC7: TL072P; DIL08
IC11, IC12: 78L09; TO92
L1, L2: BL01RN1A
LINK1, LINK2: MA03-2
LINK3: MA05-2
PULSES: MA08-2
R1, R8, R14, R15, R16, R24: 10k; 0207/7
R4: 100k; 0207/7
R6: 47k; 0207/7
SHIFTREG_EXT: 4015; DIL16
SHIFTREG_MAIN: 4015; DIL16
SV1: 10_PIN_HEADER; MA05-2
SWITCH_IC: 4016; DIL14

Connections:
+9V_1: BUFFER2.1 (VDD), C24.2, IC11.1 (VO)
+9V_2: BUFFER1.1 (VDD), C25.2, IC12.1 (VO)
+12V_BACK: AND_1.14 (VDD), AND_2.14 (VDD), C5.1 (+), C19.1, C20.1, C21.1, C22.1, C23.2, GATES.15, GATES.16, IC7.8 (V+), IC11.3 (VI), IC12.3 (VI), L1.2, LINK2.5, LINK2.6, PULSES.15, PULSES.16, R1.2, R24.2, SHIFTREG_EXT.16 (VDD), SHIFTREG_MAIN.16 (VDD), SWITCH_IC.14 (VDD)
+12V_INLET: +FUSE.1, D5.C, SV1.9, SV1.10
-12V_BACK: C6.2 (-), GATES.11, GATES.12, IC7.4 (V-), L2.2, LINK2.1, LINK2.2, PULSES.11, PULSES.12
-12V_INLET: -FUSE.1, D6.A, SV1.1, SV1.2
B1_BACK: AND_2.1 (I0), BUFFER2.9 (I), LINK3.1, R14.1, SHIFTREG_MAIN.2 (QD)
B2_BACK: AND_2.12 (I0), BUFFER2.11 (I), LINK3.2, SHIFTREG_MAIN.11 (QC)
B3_BACK: AND_2.5 (I0), BUFFER2.7 (I), LINK3.3, SHIFTREG_MAIN.12 (QB)
B4_BACK: AND_2.8 (I0), BUFFER2.5 (I), LINK3.4, SHIFTREG_MAIN.13 (QA)
B5_BACK: AND_1.12 (I0), BUFFER1.11 (I), LINK3.5, R8.1, SHIFTREG_MAIN.10 (QD)
B6_BACK: AND_1.8 (I0), BUFFER1.9 (I), LINK3.6, SHIFTREG_MAIN.3 (QC)
B7_BACK: AND_1.5 (I0), BUFFER1.7 (I), LINK3.7, SHIFTREG_MAIN.4 (QB)
B8_BACK: AND_1.1 (I0), BUFFER1.5 (I), LINK3.8, SHIFTREG_MAIN.5 (QA)
BUFFCLK2_BACK: AND_1.2 (I1), AND_1.6 (I1), AND_1.9 (I1), AND_1.13 (I1), BUFFER1.2 (O), GATES.9, GATES.10
BUFFCLK_BACK: AND_2.2 (I1), AND_2.6 (I1), AND_2.9 (I1), AND_2.13 (I1), BUFFER2.2 (O), PULSES.9, PULSES.10
CLOCK_BACK: BUFFER1.3 (I), BUFFER2.3 (I), LINK3.9, SHIFTREG_EXT.1 (CLK), SHIFTREG_EXT.9 (CLK), SHIFTREG_MAIN.1 (CLK), SHIFTREG_MAIN.9 (CLK)
END_OF_LOOP_BACK: LINK1.6, SWITCH_IC.1 (A), SWITCH_IC.5 (C)
GATE1: BUFFER1.4 (O), GATES.1
GATE2: BUFFER1.6 (O), GATES.2
GATE3: BUFFER1.10 (O), GATES.3
GATE4: BUFFER1.12 (O), GATES.4
GATE5: BUFFER2.4 (O), GATES.5
GATE6: BUFFER2.6 (O), GATES.6
GATE7: BUFFER2.12 (O), GATES.7
GATE8: BUFFER2.10 (O), GATES.8
GND_BACK: AND_1.7 (VSS), AND_2.7 (VSS), BUFFER1.8 (VSS), BUFFER1.14 (I), BUFFER2.8 (VSS), C1.1, C2.1, C3.1, C4.1, C5.2 (-), C6.1 (+), C19.2, C20.2, C21.2, C22.2, C23.1, C24.1, C25.1, D5.A, D6.C, GATES.13, GATES.14, IC7.3 (+IN), IC11.2 (GND), IC12.2 (GND), LINK2.3, LINK2.4, PULSES.13, PULSES.14, SHIFTREG_EXT.6 (RES), SHIFTREG_EXT.8 (VSS), SHIFTREG_EXT.14 (RES), SHIFTREG_MAIN.6 (RES), SHIFTREG_MAIN.8 (VSS), SHIFTREG_MAIN.14 (RES), SV1.3, SV1.4, SV1.5, SV1.6, SV1.7, SV1.8, SWITCH_IC.3 (B), SWITCH_IC.7 (VSS), SWITCH_IC.9 (B)
LOOP_CTRL_BACK: IC7.2 (-IN), LINK1.4, R6.1
unnamed: IC7.7 (OUT), R4.2
unnamed: R4.1, SWITCH_IC.6 (C), SWITCH_IC.13 (C)
unnamed: R1.1, SWITCH_IC.4 (A), SWITCH_IC.11 (A)
unnamed: IC7.1 (OUT), IC7.6 (-IN), R6.2
unnamed: C1.2, R8.2, SHIFTREG_MAIN.15 (D)
unnamed: R15.1, SHIFTREG_EXT.10 (QD)
unnamed: R16.2, SWITCH_IC.2 (B), SWITCH_IC.10 (B)
unnamed: C2.2, R14.2, SHIFTREG_EXT.7 (D)
unnamed: +FUSE.2, L1.1
unnamed: -FUSE.2, L2.1
unnamed: R24.1, SWITCH_IC.8 (A), SWITCH_IC.12 (C)
NOISE_BACK: IC7.5 (+IN), LINK1.1
PULSE1: AND_1.3 (O), BUFFER2.14 (I), PULSES.1
PULSE2: AND_1.4 (O), PULSES.2
PULSE3: AND_1.10 (O), PULSES.3
PULSE4: AND_1.11 (O), PULSES.4
PULSE5: AND_2.10 (O), PULSES.5
PULSE6: AND_2.4 (O), PULSES.6
PULSE7: AND_2.11 (O), PULSES.7
PULSE8: AND_2.3 (O), PULSES.8
PULSE_OUT_BACK: BUFFER2.15 (O), LINK3.10
START_OF_LOOP: C4.2, LINK1.5, R16.1, SHIFTREG_MAIN.7 (D)
STEP_12_BACK: C3.2, LINK1.3, R15.2, SHIFTREG_EXT.15 (D)
STEP_16_BACK: LINK1.2, SHIFTREG_EXT.2 (QD)

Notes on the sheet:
Shift register loop
Optional reverse polarity protection If not required, omit diodes and replace fuses with jumper wire. Don't get it the wrong way around! Ferrites: 81-BL01RN1A1D2B or 623-2743001112LF
NB: Bit numbers are reversed at this point: Bit8 = first bit (left hand LED on main module) becomes Pulse1 (Top output on expanders)

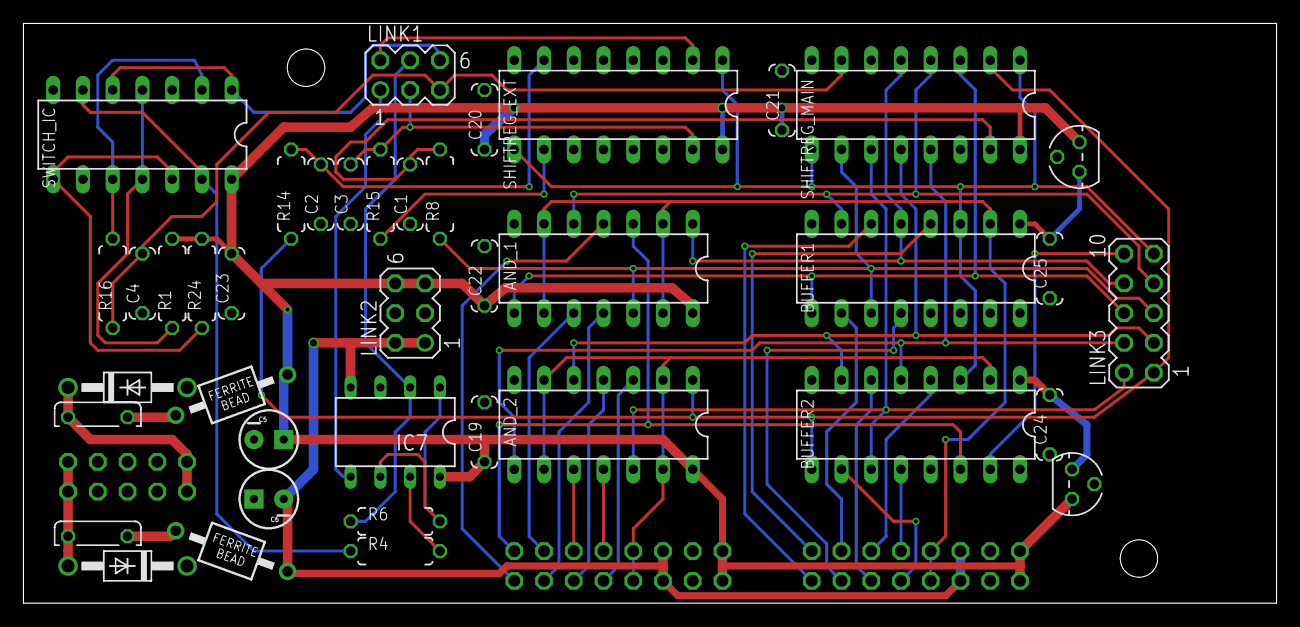
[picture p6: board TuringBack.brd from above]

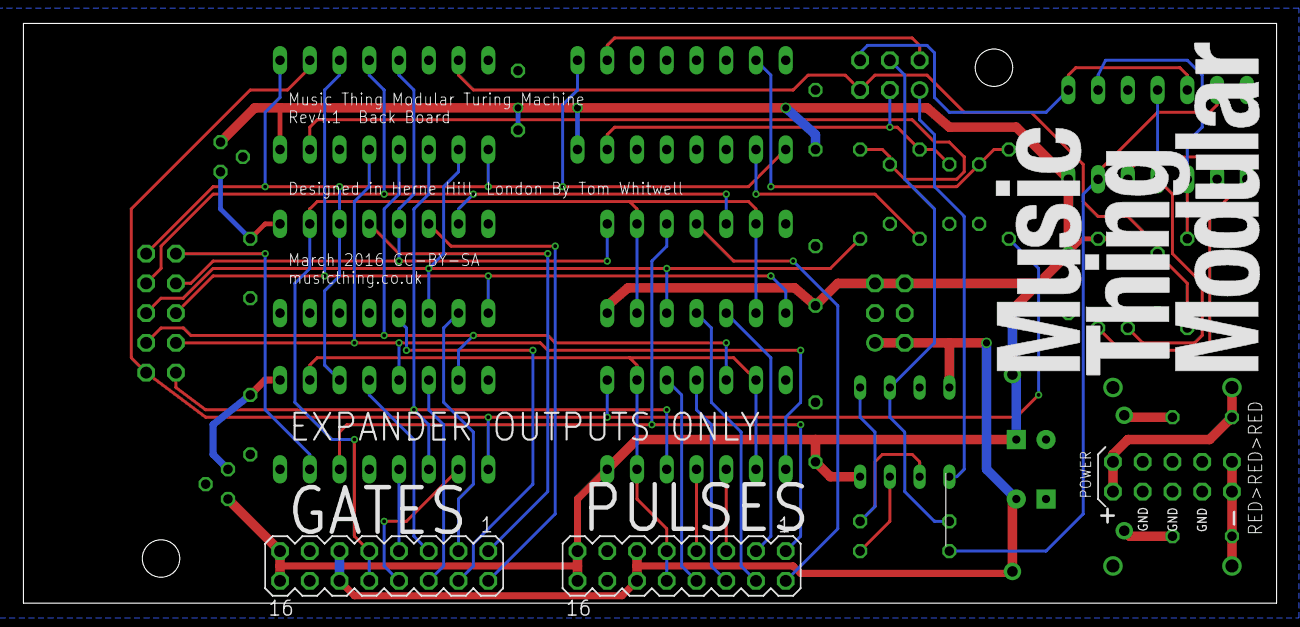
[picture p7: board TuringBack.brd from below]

Board: 4 copper layers, 107.0 x 49.5 mm, 45 parts (3 on the bottom side), 52 nets.

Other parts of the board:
U$4, U$5: MOUNTING_HOLE

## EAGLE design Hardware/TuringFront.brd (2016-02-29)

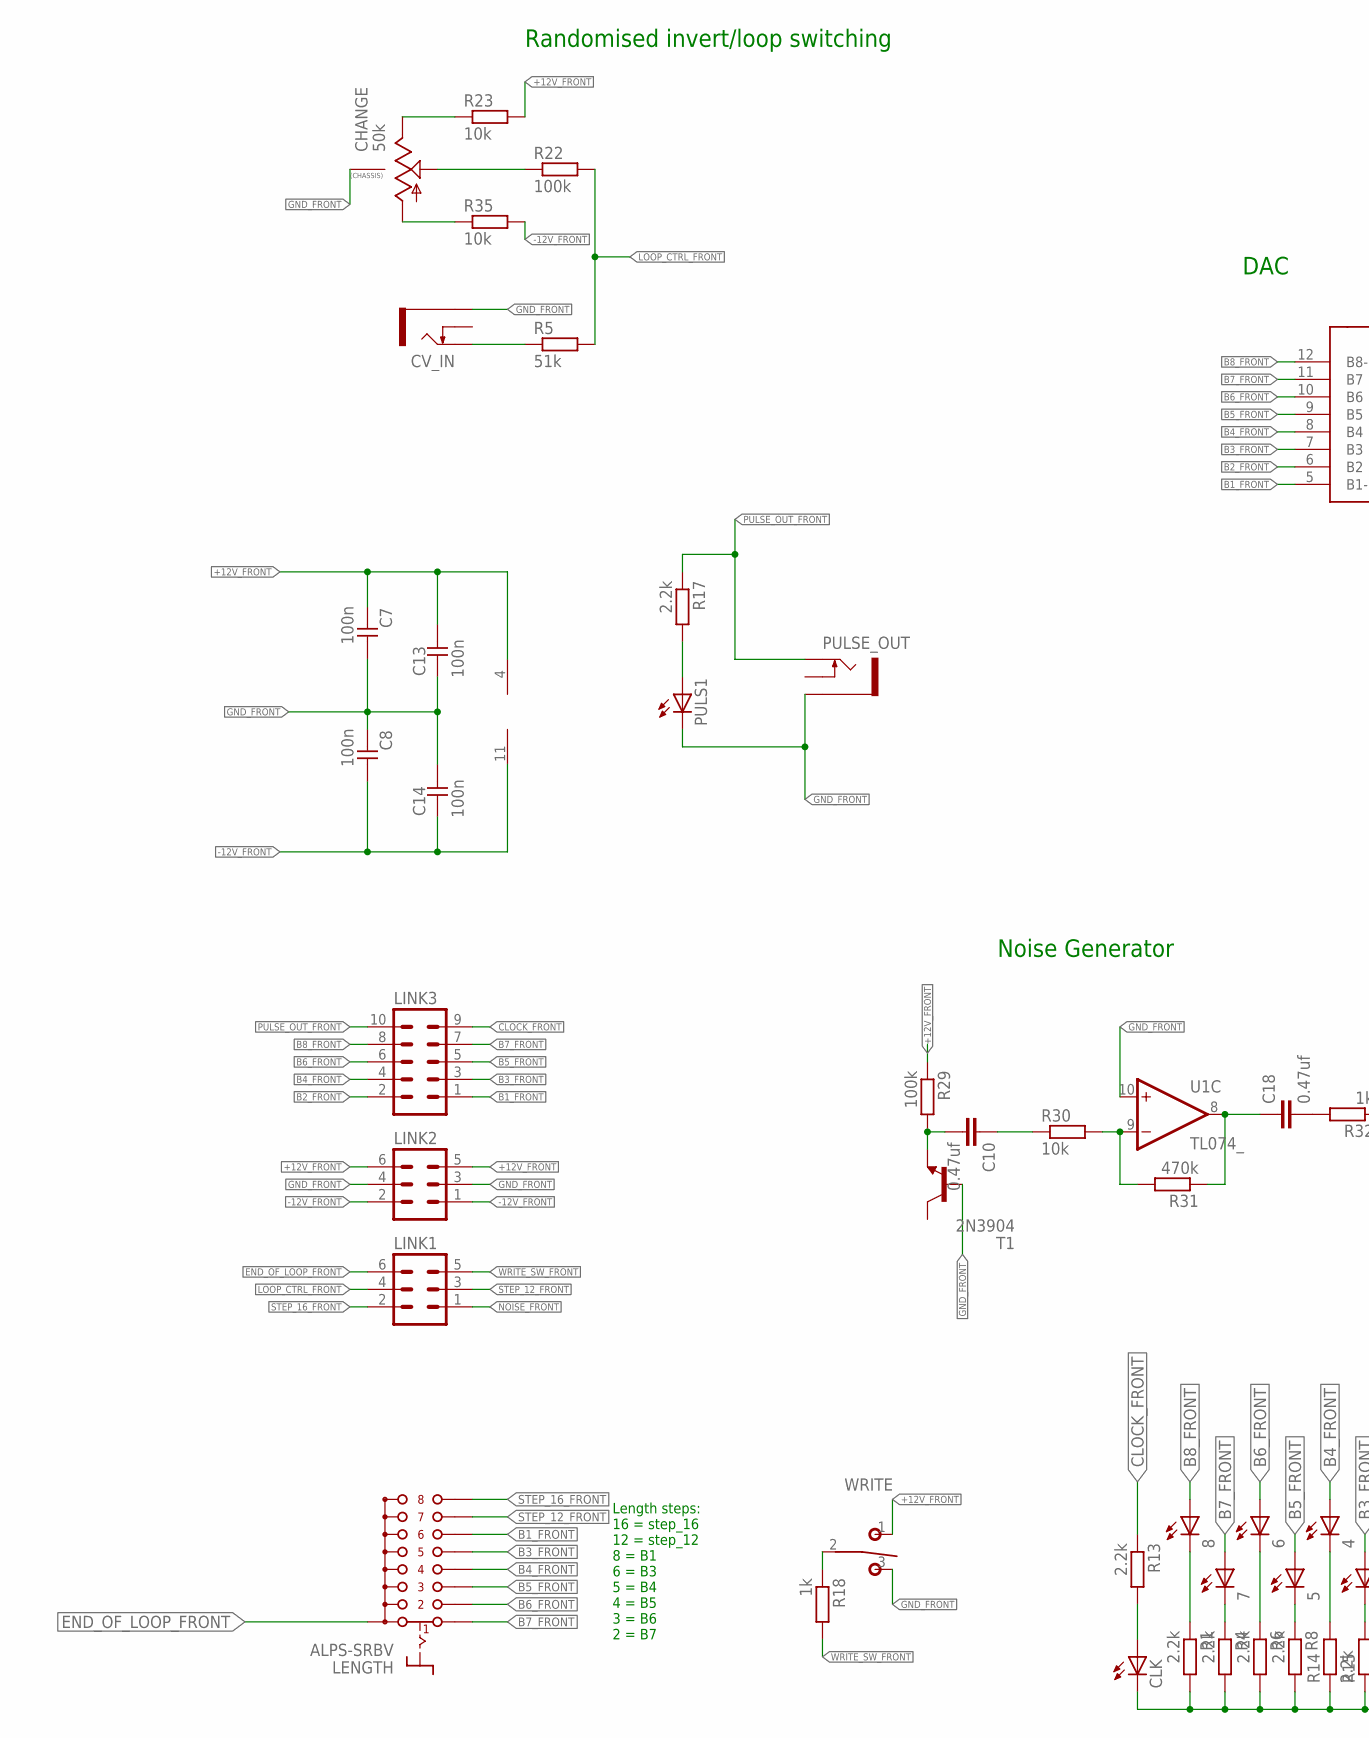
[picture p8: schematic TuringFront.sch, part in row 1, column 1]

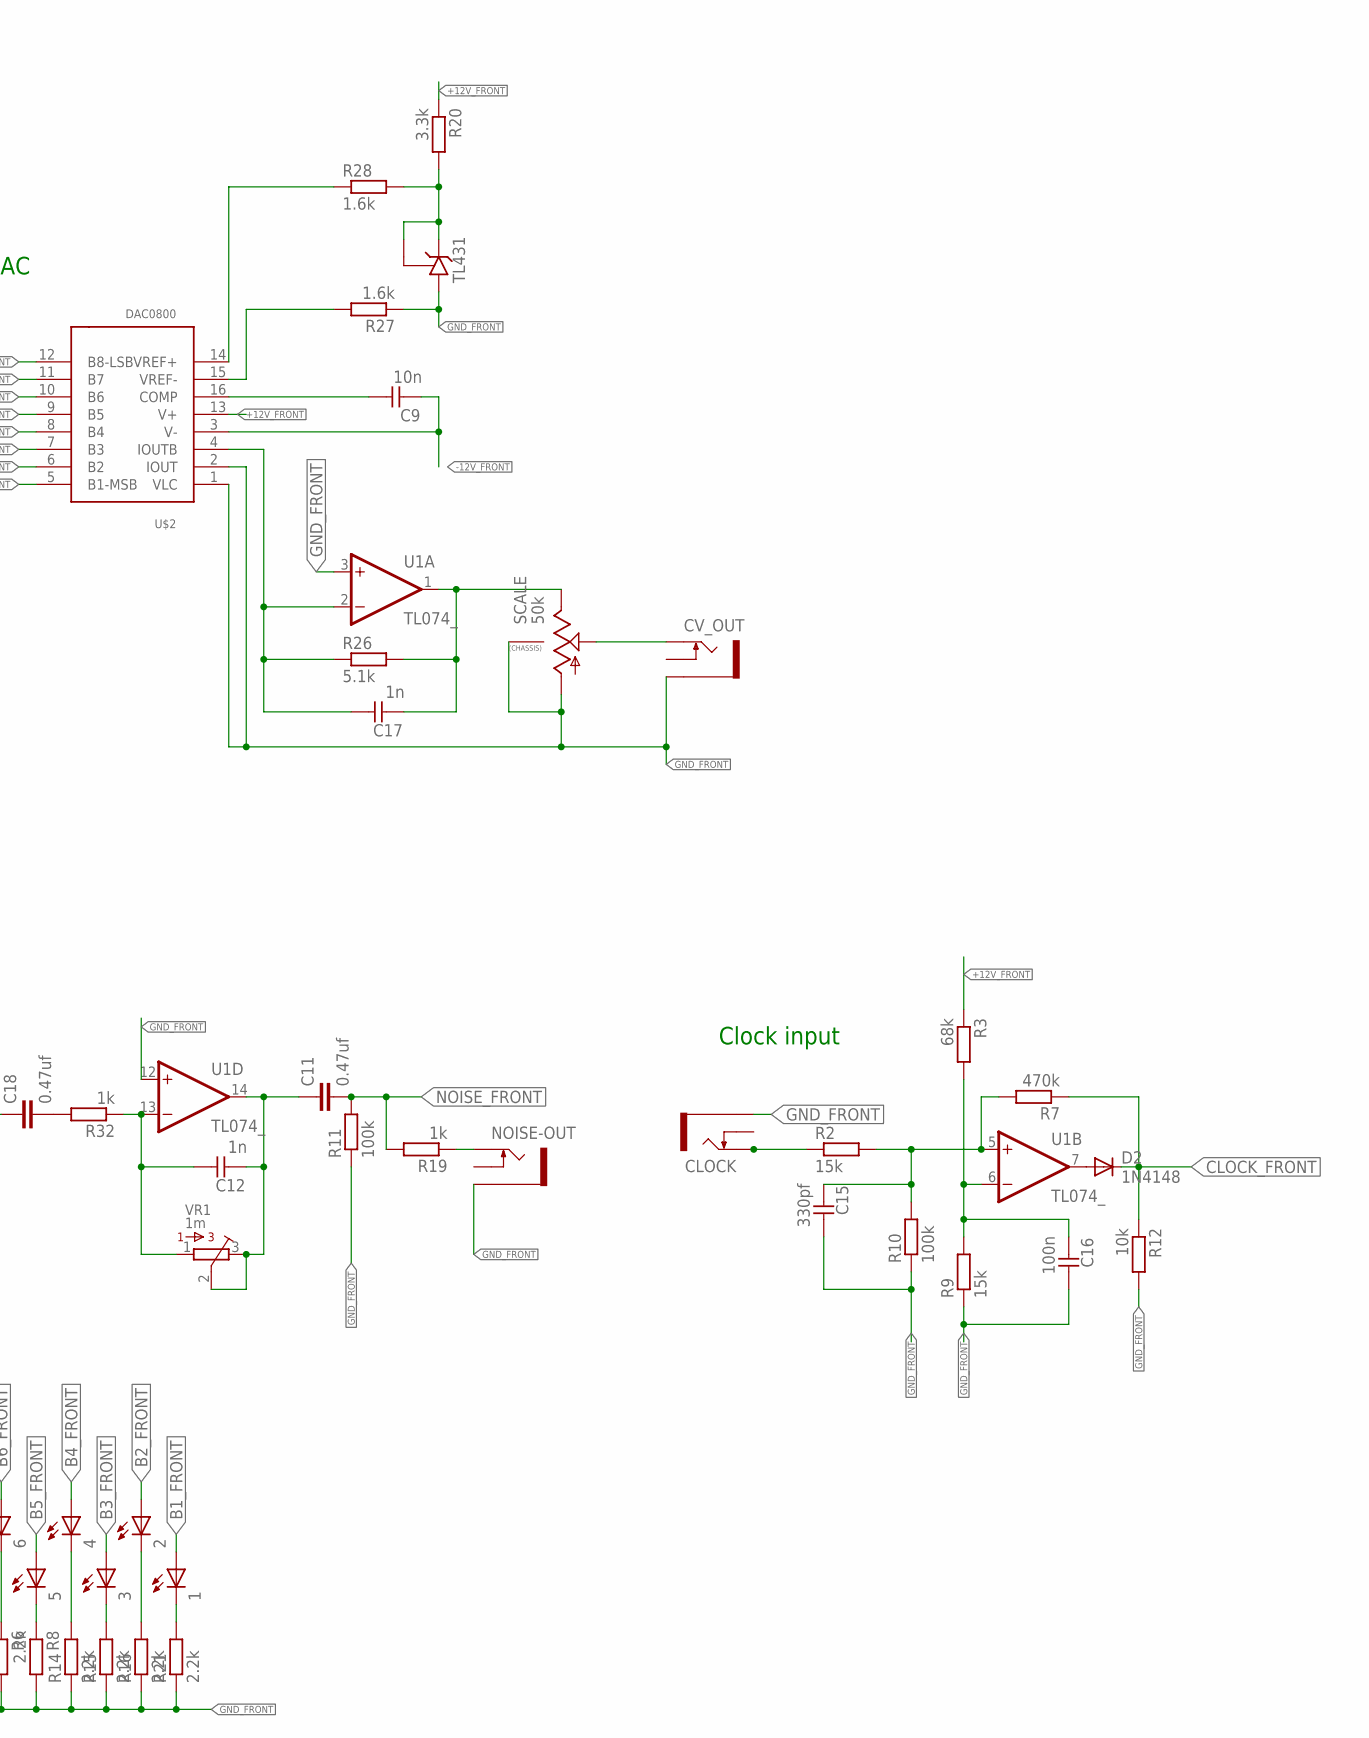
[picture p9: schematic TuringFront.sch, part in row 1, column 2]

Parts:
1, 2, 3, 4, 5, 6, 7, 8: LED3MM
C7, C8, C13, C14, C16: 100n; C050-024X044
C9: 10n; C050-024X044
C10, C11, C18: 0.47uf; C050-035X075
C12, C17: 1n; C050-024X044
C15: 330pf; C050-024X044
CHANGE: 50k; 9MM_SNAP-IN_POT
CLK: LED3MM
CLOCK: THONKICONNNEW; WQP-PJ301M-12_JACK
CV_IN: THONKICONNNEW; WQP-PJ301M-12_JACK
CV_OUT: THONKICONNNEW; WQP-PJ301M-12_JACK
D2: 1N4148; DO35-7
LENGTH: ALPS-SRBV
LINK1, LINK2: MA03-2BACKSIDE
LINK3: 10PIN_BACKSIDE
NOISE-OUT: THONKICONNNEW; WQP-PJ301M-12_JACK
PULS1: LED3MM
PULSE_OUT: THONKICONNNEW; WQP-PJ301M-12_JACK
R1, R4, R6, R8, R13, R14, R15, R16, R17, R21: 2.2k; 0207/7
R2, R9: 15k; 0207/7
R3: 68k; 0207/7
R5: 51k; 0207/7
R7, R31: 470k; 0207/7
R10, R22, R29: 100k; 0207/7
R11: 100k; 7MM_RESISTOR
R12, R23, R30, R35: 10k; 0207/7
R18, R19, R32: 1k; 0207/7
R20: 3.3k; 0207/7
R26: 5.1k; 0207/7
R27, R28: 1.6k; 0207/7
SCALE: 50k; 9MM_SNAP-IN_POT
T1: 2N3904; TO92
TL431: TL431CLP; TO92-CLP
U1: TL074_; DIL14
U$2: DAC0800; DIL16
VR1: 1m; BOURNS_3362P_TRIMMER
WRITE: T-80-T-SPDT-ON-OFF-ON; M9040P

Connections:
+12V_FRONT: C7.2, C13.1, LINK2.5, LINK2.6, R3.1, R20.1, R23.2, R29.1, U1.4 (V+), U$2.13 (V+), WRITE.1 (O)
-12V_FRONT: C8.1, C9.2, C14.2, LINK2.1, LINK2.2, R35.2, U1.11 (V-), U$2.3 (V-)
B1_FRONT: 1.A, LENGTH.F (6), LINK3.1, U$2.5 (B1-MSB)
B2_FRONT: 2.A, LINK3.2, U$2.6 (B2)
B3_FRONT: 3.A, LENGTH.E (5), LINK3.3, U$2.7 (B3)
B4_FRONT: 4.A, LENGTH.D (4), LINK3.4, U$2.8 (B4)
B5_FRONT: 5.A, LENGTH.C (3), LINK3.5, U$2.9 (B5)
B6_FRONT: 6.A, LENGTH.B (2), LINK3.6, U$2.10 (B6)
B7_FRONT: 7.A, LENGTH.A (1), LINK3.7, U$2.11 (B7)
B8_FRONT: 8.A, LINK3.8, U$2.12 (B8-LSB)
CLOCK_FRONT: D2.C, LINK3.9, R7.1, R12.1, R13.1
END_OF_LOOP_FRONT: LENGTH.COM (A), LENGTH.COM2 (A), LINK1.6
GND_FRONT: C7.1, C8.2, C13.2, C14.1, C15.1, C16.1, CHANGE.CHASSIS2, CLK.K (C), CLOCK.P$3_SLEEVE (SLEEVE), CV_IN.P$3_SLEEVE (SLEEVE), CV_OUT.P$3_SLEEVE (SLEEVE), LINK2.3, LINK2.4, NOISE-OUT.P$3_SLEEVE (SLEEVE), PULS1.K (C), PULSE_OUT.P$3_SLEEVE (SLEEVE), R1.2, R4.2, R6.2, R8.2, R9.1, R10.1, R11.1, R12.2, R14.1, R15.1, R16.1, R21.1, R27.1, SCALE.1 (A), SCALE.CHASSIS2, T1.2 (B), TL431.A, U1.3 (+IN), U1.10 (+IN), U1.12 (+IN), U$2.1 (VLC), U$2.2 (IOUT), WRITE.3 (S)
LOOP_CTRL_FRONT: LINK1.4, R5.2, R22.2
MAIN_OUT: C17.2, R26.2, SCALE.3 (E), U1.1 (OUT)
unnamed: CLOCK.P$1_TIP (TIP), R2.1
unnamed: CV_IN.P$1_TIP (TIP), R5.1
unnamed: C15.2, R2.2, R7.2, R10.2, U1.5 (+IN)
unnamed: PULS1.A, R17.2
unnamed: D2.A, U1.7 (OUT)
unnamed: C18.2, R32.2
unnamed: R18.1, WRITE.2
unnamed: C16.2, R3.2, R9.2, U1.6 (-IN)
unnamed: C17.1, R26.1, U1.2 (-IN), U$2.4 (IOUTB)
unnamed: CLK.A, R13.2
unnamed: C10.2, R29.2, T1.3 (E)
unnamed: R20.2, R28.2, TL431.C, TL431.R
unnamed: C10.1, R30.1
unnamed: R30.2, R31.2, U1.9 (-IN)
unnamed: C18.1, R31.1, U1.8 (OUT)
unnamed: R27.2, U$2.15 (VREF-)
unnamed: C9.1, U$2.16 (COMP)
unnamed: R28.1, U$2.14 (VREF+)
unnamed: C12.1, R32.1, U1.13 (-IN), VR1.1
unnamed: 8.K (C), R1.1
unnamed: 7.K (C), R4.1
unnamed: 6.K (C), R6.1
unnamed: 5.K (C), R8.1
unnamed: 4.K (C), R14.2
unnamed: 3.K (C), R15.2
unnamed: 2.K (C), R16.2
unnamed: 1.K (C), R21.2
unnamed: CV_OUT.P$1_TIP (TIP), SCALE.2 (S)
unnamed: NOISE-OUT.P$1_TIP (TIP), R19.1
unnamed: C11.1, C12.2, U1.14 (OUT), VR1.2, VR1.3
unnamed: CHANGE.2 (S), R22.1
unnamed: CHANGE.3 (E), R23.1
unnamed: CHANGE.1 (A), R35.1
NOISE_FRONT: C11.2, LINK1.1, R11.2, R19.2
PULSE_OUT_FRONT: LINK3.10, PULSE_OUT.P$1_TIP (TIP), R17.1
STEP_12_FRONT: LENGTH.G (7), LINK1.3
STEP_16_FRONT: LENGTH.H (8), LINK1.2
WRITE_SW_FRONT: LINK1.5, R18.2

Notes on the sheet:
Randomised invert/loop switching
Length steps: 16 = step_16 12 = step_12 8 = B1 6 = B3 5 = B4 4 = B5 3 = B6 2 = B7
Noise Generator
Clock input
DAC

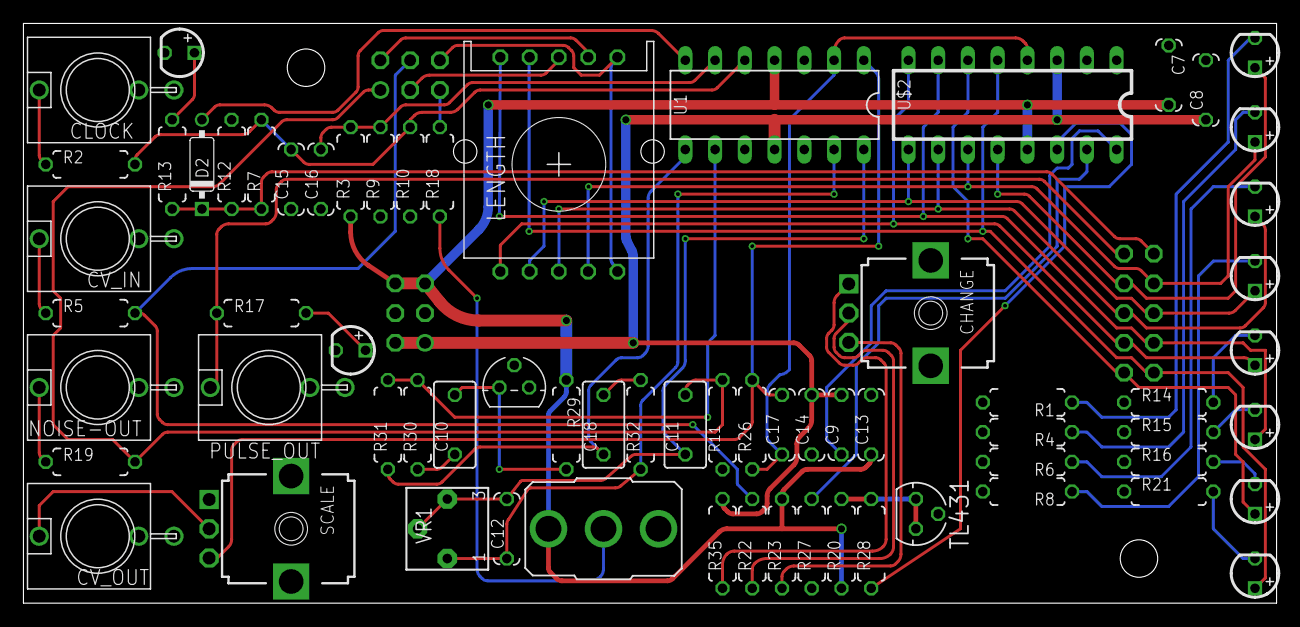
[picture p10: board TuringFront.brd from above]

Board: 4 copper layers, 107.0 x 49.5 mm, 73 parts (0 on the bottom side), 53 nets.

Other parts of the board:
U$4, U$5: MOUNTING_HOLE

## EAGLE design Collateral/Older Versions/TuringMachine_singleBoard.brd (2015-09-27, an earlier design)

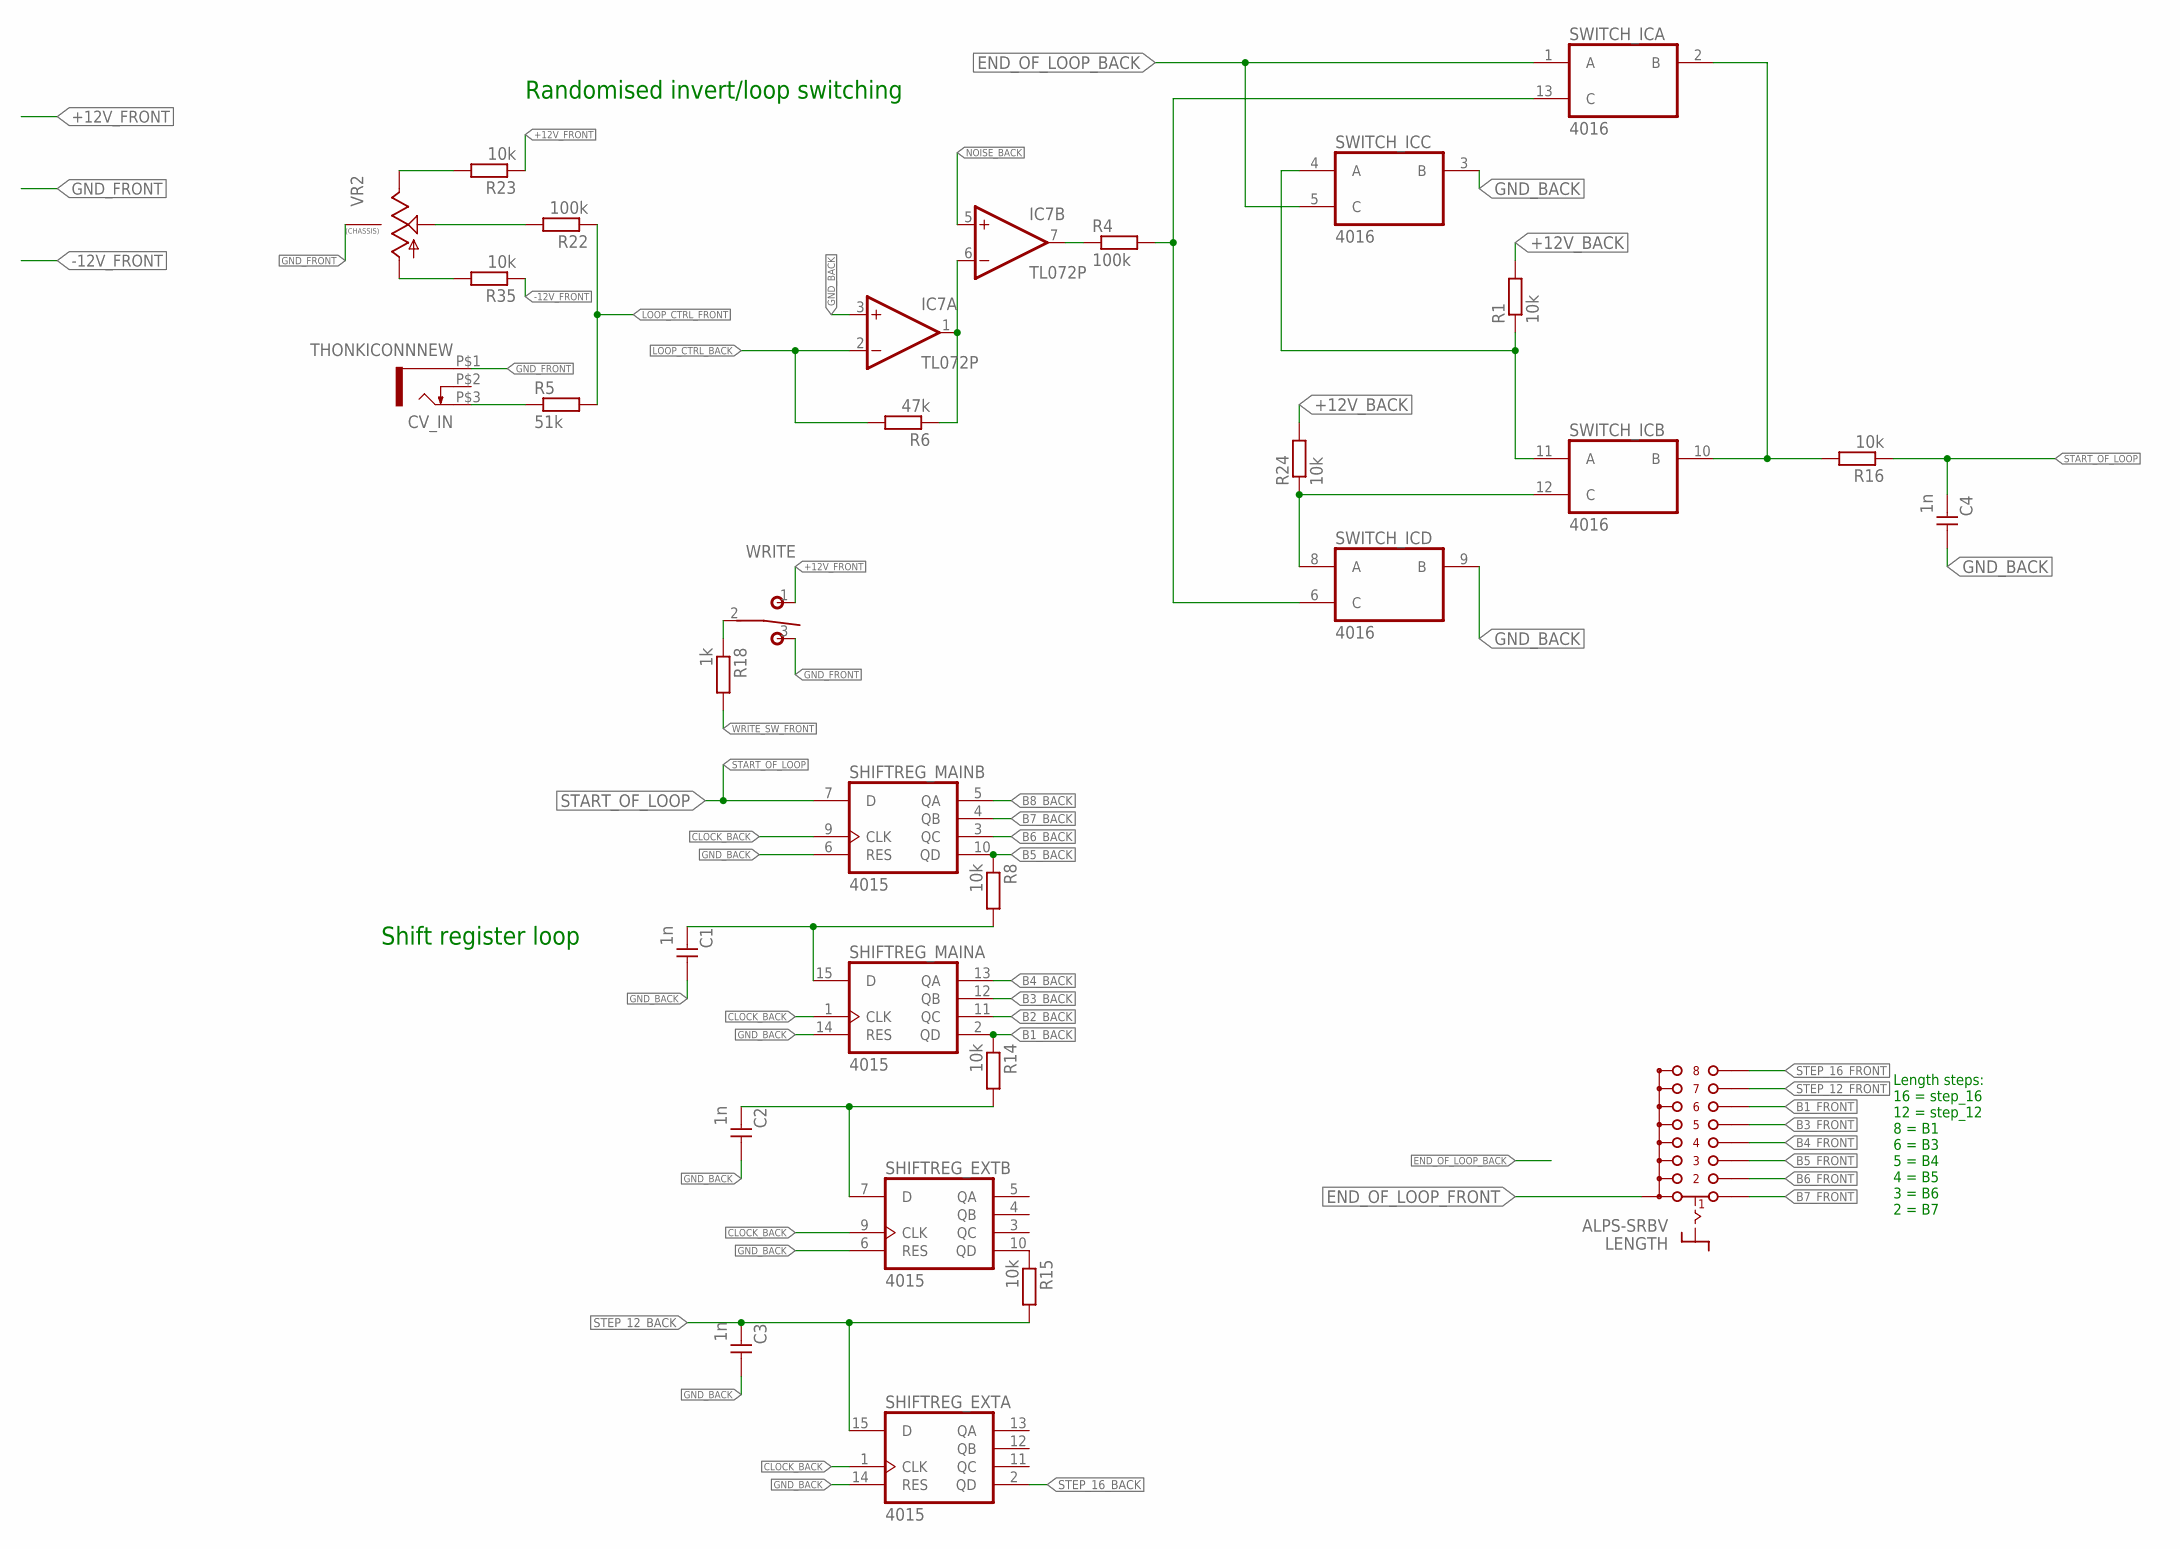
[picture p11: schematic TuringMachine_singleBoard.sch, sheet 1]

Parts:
C1, C2, C3, C4: 1n; C050-024X044
CV_IN: THONKICONNNEW; WQP-PJ301M-12_JACK
IC7: TL072P; DIL08
LENGTH: ALPS-SRBV
R1, R8, R14, R15, R16, R23, R24, R35: 10k; 0207/7
R4, R22: 100k; 0207/7
R5: 51k; 0207/7
R6: 47k; 0207/7
R18: 1k; 0207/7
SHIFTREG_EXT: 4015; DIL16
SHIFTREG_MAIN: 4015; DIL16
SWITCH_IC: 4016; DIL14
VR2: 9MM_SNAP-IN_POT_CHASSIS; 9MM_SNAP-IN_POT
WRITE: T-80-T-SPDT-ON-OFF-ON; M9040P

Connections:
+12V_BACK: R1.2, R24.2; also elsewhere on the board
+12V_FRONT: R23.1, WRITE.1 (O); also elsewhere on the board
-12V_FRONT: R35.1; also elsewhere on the board
B1_BACK: R14.1, SHIFTREG_MAIN.2 (QD); also elsewhere on the board
B1_FRONT: LENGTH.F (6); also elsewhere on the board
B2_BACK: SHIFTREG_MAIN.11 (QC); also elsewhere on the board
B3_BACK: SHIFTREG_MAIN.12 (QB); also elsewhere on the board
B3_FRONT: LENGTH.E (5); also elsewhere on the board
B4_BACK: SHIFTREG_MAIN.13 (QA); also elsewhere on the board
B4_FRONT: LENGTH.D (4); also elsewhere on the board
B5_BACK: R8.1, SHIFTREG_MAIN.10 (QD); also elsewhere on the board
B5_FRONT: LENGTH.C (3); also elsewhere on the board
B6_BACK: SHIFTREG_MAIN.3 (QC); also elsewhere on the board
B6_FRONT: LENGTH.B (2); also elsewhere on the board
B7_BACK: SHIFTREG_MAIN.4 (QB); also elsewhere on the board
B7_FRONT: LENGTH.A (1); also elsewhere on the board
B8_BACK: SHIFTREG_MAIN.5 (QA); also elsewhere on the board
CLOCK_BACK: SHIFTREG_EXT.1 (CLK), SHIFTREG_EXT.9 (CLK), SHIFTREG_MAIN.1 (CLK), SHIFTREG_MAIN.9 (CLK); also elsewhere on the board
END_OF_LOOP_BACK: SWITCH_IC.1 (A), SWITCH_IC.5 (C); also elsewhere on the board
END_OF_LOOP_FRONT: LENGTH.COM (A), LENGTH.COM2 (A); also elsewhere on the board
GND_BACK: C1.1, C2.1, C3.1, C4.1, IC7.3 (+IN), SHIFTREG_EXT.6 (RES), SHIFTREG_EXT.14 (RES), SHIFTREG_MAIN.6 (RES), SHIFTREG_MAIN.14 (RES), SWITCH_IC.3 (B), SWITCH_IC.9 (B); also elsewhere on the board
GND_FRONT: CV_IN.P$1 (5), VR2.M1, VR2.M2, WRITE.3 (S); also elsewhere on the board
LOOP_CTRL_BACK: IC7.2 (-IN), R4.2, R6.2, SWITCH_IC.6 (C), SWITCH_IC.13 (C); also elsewhere on the board
LOOP_CTRL_FRONT: R5.2, R22.1; also elsewhere on the board
unnamed: IC7.7 (OUT), R4.1
unnamed: CV_IN.P$3 (3), R5.1
unnamed: R1.1, SWITCH_IC.4 (A), SWITCH_IC.11 (A)
unnamed: IC7.1 (OUT), IC7.6 (-IN), R6.1
unnamed: C1.2, R8.2, SHIFTREG_MAIN.15 (D)
unnamed: R18.1, WRITE.2
unnamed: R15.1, SHIFTREG_EXT.10 (QD)
unnamed: R16.2, SWITCH_IC.2 (B), SWITCH_IC.10 (B)
unnamed: C2.2, R14.2, SHIFTREG_EXT.7 (D)
unnamed: R22.2, VR2.2 (S)
unnamed: R24.1, SWITCH_IC.8 (A), SWITCH_IC.12 (C)
unnamed: R23.2, VR2.3 (E)
unnamed: R35.2, VR2.1 (A)
NOISE_BACK: IC7.5 (+IN); also elsewhere on the board
START_OF_LOOP: C4.2, R16.1, SHIFTREG_MAIN.7 (D); also elsewhere on the board
STEP_12_BACK: C3.2, R15.2, SHIFTREG_EXT.15 (D); also elsewhere on the board
STEP_12_FRONT: LENGTH.G (7); also elsewhere on the board
STEP_16_BACK: SHIFTREG_EXT.2 (QD); also elsewhere on the board
STEP_16_FRONT: LENGTH.H (8); also elsewhere on the board
WRITE_SW_FRONT: R18.2; also elsewhere on the board

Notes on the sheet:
Randomised invert/loop switching
Shift register loop
Length steps: 16 = step_16 12 = step_12 8 = B1 6 = B3 5 = B4 4 = B5 3 = B6 2 = B7

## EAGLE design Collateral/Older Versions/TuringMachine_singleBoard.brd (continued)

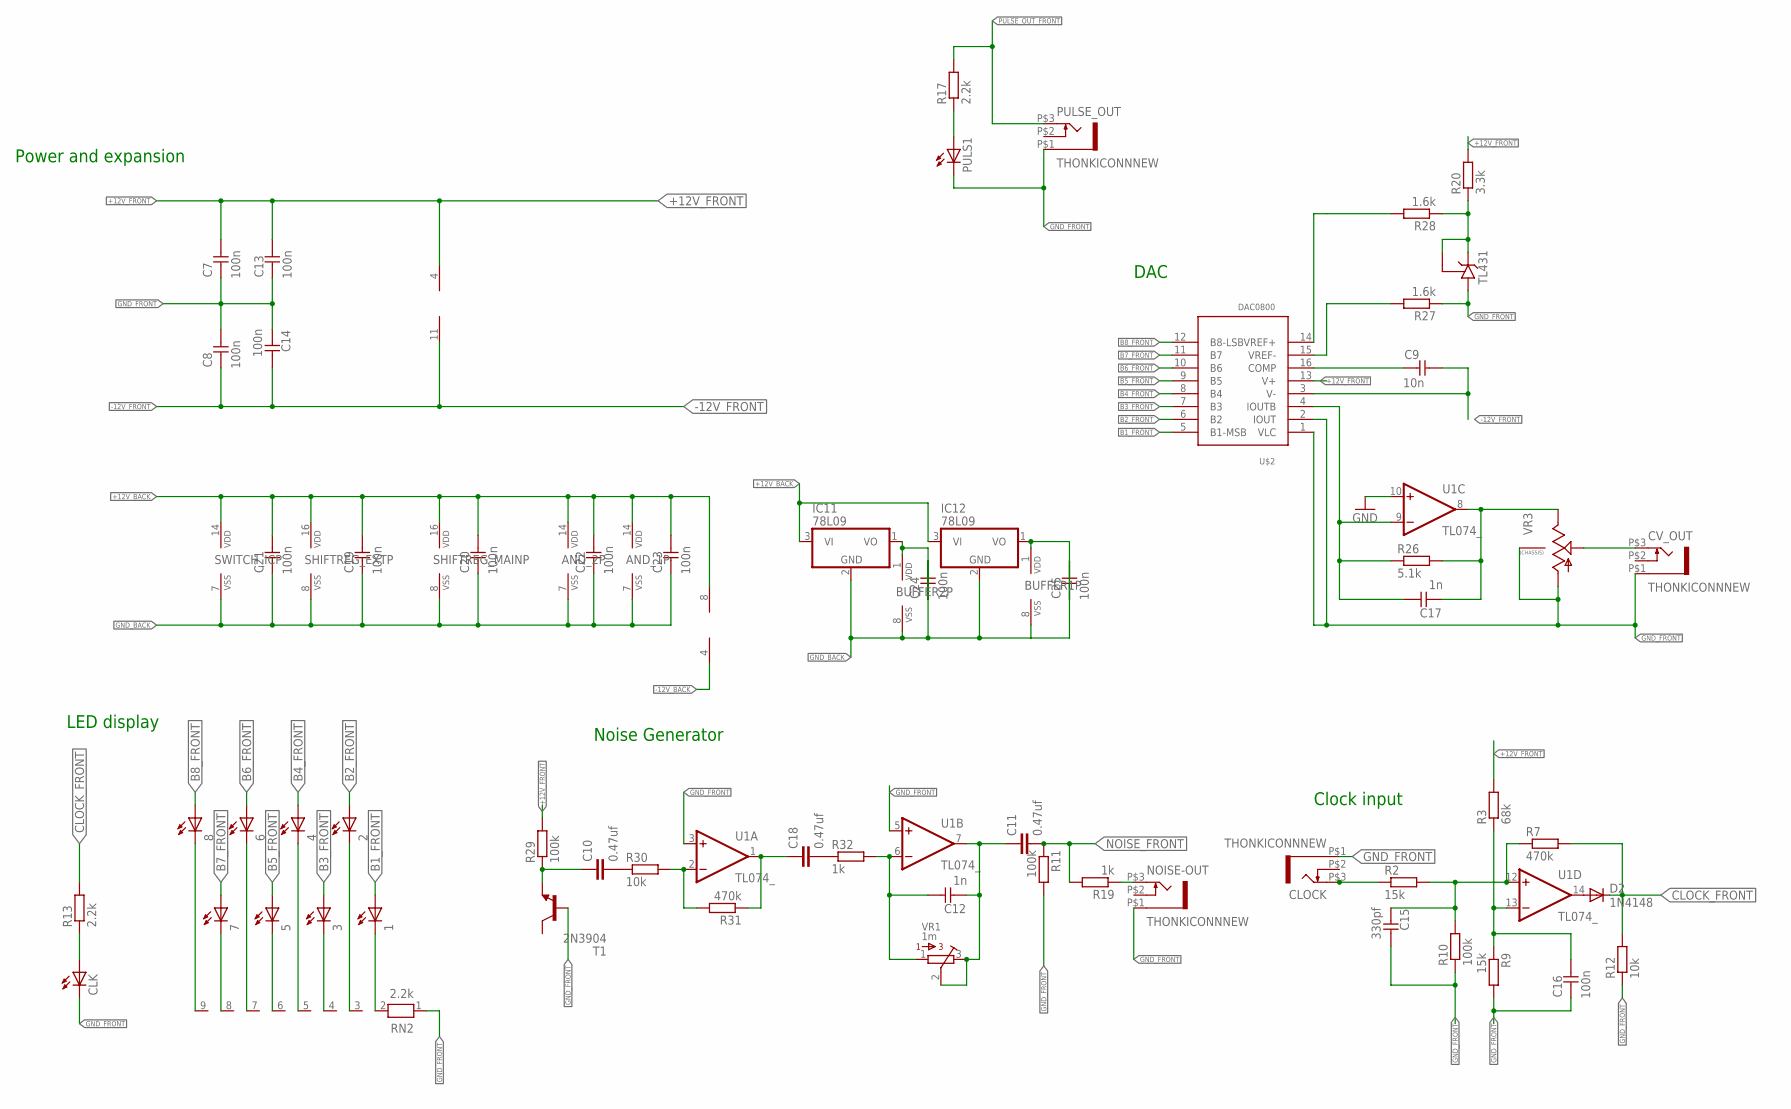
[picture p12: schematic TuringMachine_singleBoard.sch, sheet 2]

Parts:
1, 2, 3, 4, 5, 6, 7, 8: LED3MM
AND_1, AND_2: 4081; DIL14
BUFFER1, BUFFER2: 4050; DIL16
C7, C8, C13, C14, C16, C19, C20, C21, C22, C23, C24, C25: 100n; C050-024X044
C9: 10n; C050-024X044
C10, C11, C18: 0.47uf; C050-035X075
C12, C17: 1n; C050-024X044
C15: 330pf; C050-024X044
CLK: LED3MM
CLOCK: THONKICONNNEW; WQP-PJ301M-12_JACK
CV_OUT: THONKICONNNEW; WQP-PJ301M-12_JACK
D2: 1N4148; DO35-7
IC7: TL072P; DIL08
IC11, IC12: 78L09; TO92
NOISE-OUT: THONKICONNNEW; WQP-PJ301M-12_JACK
PULS1: LED3MM
PULSE_OUT: THONKICONNNEW; WQP-PJ301M-12_JACK
R2, R9: 15k; 0207/7
R3: 68k; 0207/7
R7, R31: 470k; 0207/7
R10, R29: 100k; 0207/7
R11: 100k; 7MM_RESISTOR
R12, R30: 10k; 0207/7
R13, R17: 2.2k; 0207/7
R19, R32: 1k; 0207/7
R20: 3.3k; 0207/7
R26: 5.1k; 0207/7
R27, R28: 1.6k; 0207/7
RN2: 2.2k; RN-9
SHIFTREG_EXT: 4015; DIL16
SHIFTREG_MAIN: 4015; DIL16
SWITCH_IC: 4016; DIL14
T1: 2N3904; TO92
TL431: TL431CLP; TO92-CLP
U1: TL074_; DIL14
U$2: DAC0800; DIL16
VR1: 1m; BOURNS_3362P_TRIMMER
VR3: 9MM_SNAP-IN_POT_CHASSIS; 9MM_SNAP-IN_POT

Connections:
+9V_1: BUFFER2.1 (VDD), C24.2, IC11.1 (VO)
+9V_2: BUFFER1.1 (VDD), C25.2, IC12.1 (VO)
+12V_BACK: AND_1.14 (VDD), AND_2.14 (VDD), C19.1, C20.1, C21.1, C22.1, C23.1, IC7.8 (V+), IC11.3 (VI), IC12.3 (VI), SHIFTREG_EXT.16 (VDD), SHIFTREG_MAIN.16 (VDD), SWITCH_IC.14 (VDD); also elsewhere on the board
+12V_FRONT: C7.1, C13.1, R3.2, R20.2, R29.2, U1.4 (V+), U$2.13 (V+); also elsewhere on the board
-12V_BACK: IC7.4 (V-); also elsewhere on the board
-12V_FRONT: C8.2, C9.1, C14.1, U1.11 (V-), U$2.3 (V-); also elsewhere on the board
B1_FRONT: 1.A, U$2.5 (B1-MSB); also elsewhere on the board
B2_FRONT: 2.A, U$2.6 (B2); also elsewhere on the board
B3_FRONT: 3.A, U$2.7 (B3); also elsewhere on the board
B4_FRONT: 4.A, U$2.8 (B4); also elsewhere on the board
B5_FRONT: 5.A, U$2.9 (B5); also elsewhere on the board
B6_FRONT: 6.A, U$2.10 (B6); also elsewhere on the board
B7_FRONT: 7.A, U$2.11 (B7); also elsewhere on the board
B8_FRONT: 8.A, U$2.12 (B8-LSB); also elsewhere on the board
CLOCK_FRONT: D2.C, R7.2, R12.2, R13.2; also elsewhere on the board
GND_BACK: AND_1.7 (VSS), AND_2.7 (VSS), BUFFER1.8 (VSS), BUFFER2.8 (VSS), C19.2, C20.2, C21.2, C22.2, C23.2, C24.1, C25.1, IC11.2 (GND), IC12.2 (GND), SHIFTREG_EXT.8 (VSS), SHIFTREG_MAIN.8 (VSS), SWITCH_IC.7 (VSS); also elsewhere on the board
GND_FRONT: C7.2, C8.1, C13.2, C14.2, C15.1, C16.2, CLK.K (C), CLOCK.P$1 (5), CV_OUT.P$1 (5), NOISE-OUT.P$1 (5), PULS1.K (C), PULSE_OUT.P$1 (5), R9.2, R10.1, R11.2, R12.1, R27.1, RN2.1, T1.2 (B), TL431.A, U1.3 (+IN), U1.5 (+IN), U1.10 (+IN), U$2.1 (VLC), U$2.2 (IOUT), VR3.1 (A), VR3.M1, VR3.M2; also elsewhere on the board
MAIN_OUT: C17.2, R26.2, U1.8 (OUT), VR3.3 (E)
unnamed: CLOCK.P$3 (3), R2.1
unnamed: C15.2, R2.2, R7.1, R10.2, U1.12 (+IN)
unnamed: PULS1.A, R17.1
unnamed: D2.A, U1.14 (OUT)
unnamed: C18.2, R32.1
unnamed: C16.1, R3.1, R9.1, U1.13 (-IN)
unnamed: C17.1, R26.1, U1.9 (-IN), U$2.4 (IOUTB)
unnamed: CLK.A, R13.1
unnamed: C10.1, R29.1, T1.3 (E)
unnamed: R20.1, R28.1, TL431.C, TL431.R
unnamed: C10.2, R30.1
unnamed: R30.2, R31.2, U1.2 (-IN)
unnamed: C18.1, R31.1, U1.1 (OUT)
unnamed: R27.2, U$2.15 (VREF-)
unnamed: C9.2, U$2.16 (COMP)
unnamed: R28.2, U$2.14 (VREF+)
unnamed: C12.1, R32.2, U1.6 (-IN), VR1.1
unnamed: 8.K (C), RN2.9
unnamed: 7.K (C), RN2.8
unnamed: 6.K (C), RN2.7
unnamed: 5.K (C), RN2.6
unnamed: 4.K (C), RN2.5
unnamed: 3.K (C), RN2.4
unnamed: 2.K (C), RN2.3
unnamed: 1.K (C), RN2.2
unnamed: CV_OUT.P$3 (3), VR3.2 (S)
unnamed: NOISE-OUT.P$3 (3), R19.1
unnamed: C11.1, C12.2, U1.7 (OUT), VR1.2, VR1.3
NOISE_FRONT: C11.2, R11.1, R19.2; also elsewhere on the board
PULSE_OUT_FRONT: PULSE_OUT.P$3 (3), R17.2; also elsewhere on the board

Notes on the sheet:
LED display
Noise Generator
Clock input
Power and expansion
DAC

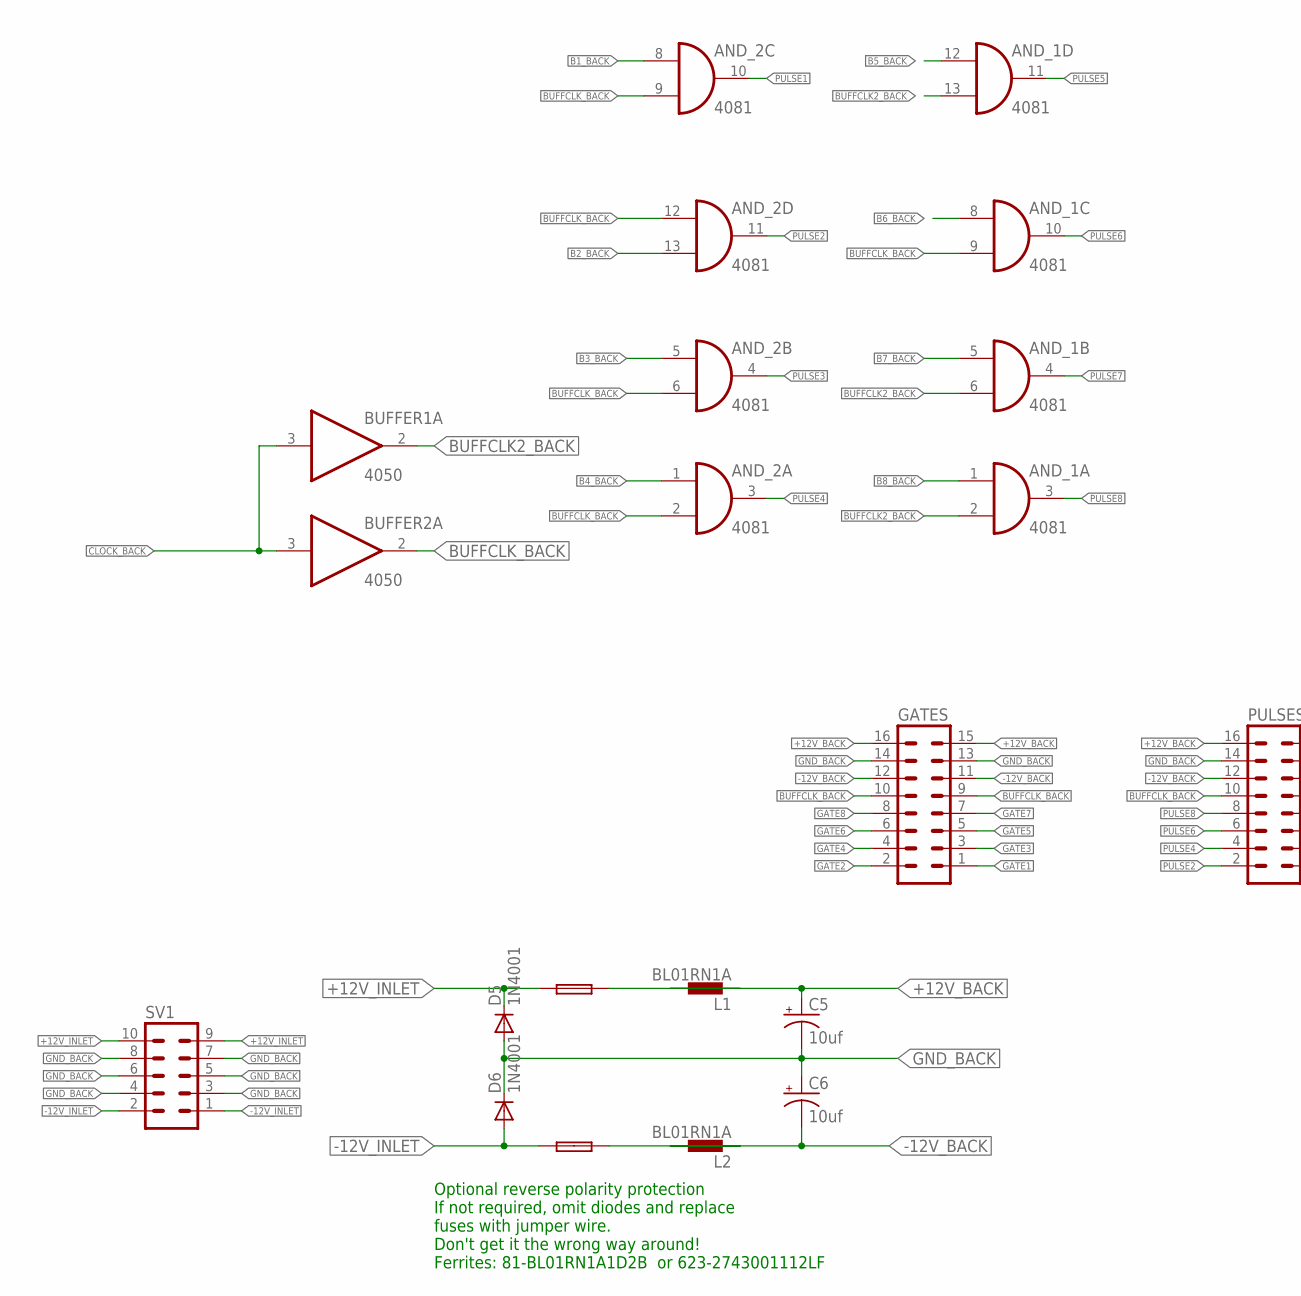
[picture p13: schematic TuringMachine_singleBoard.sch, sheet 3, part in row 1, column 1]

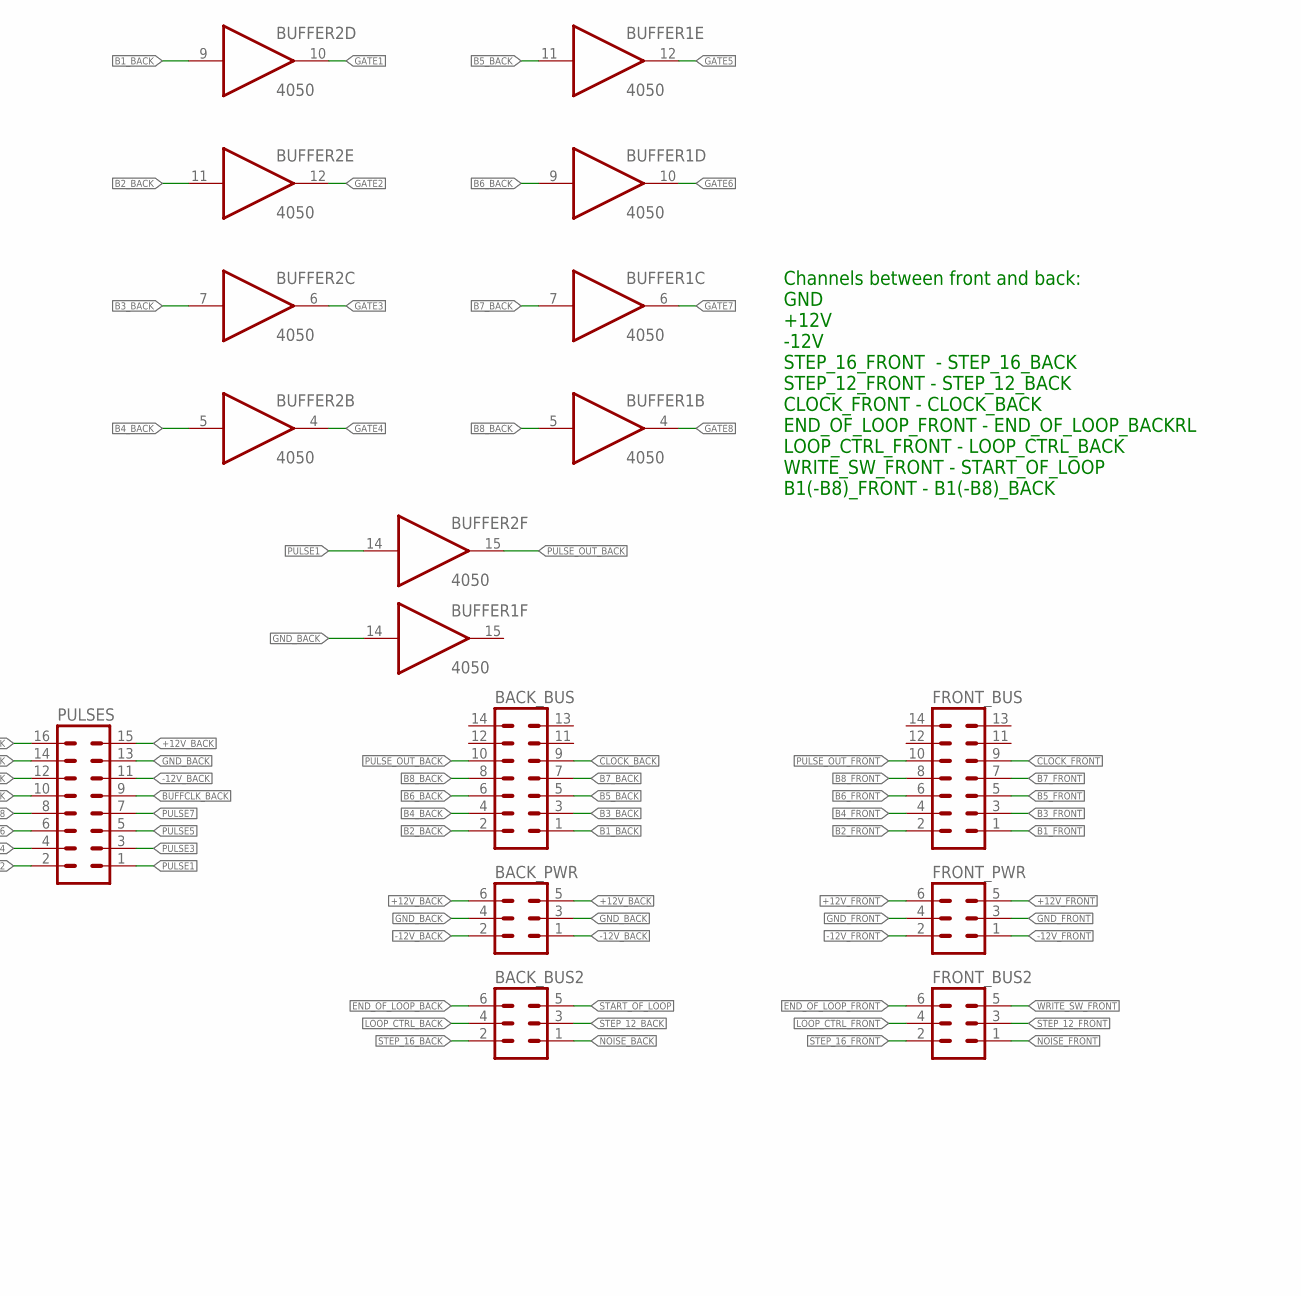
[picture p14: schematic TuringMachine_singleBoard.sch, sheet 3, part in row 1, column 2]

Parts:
AND_1, AND_2: 4081; DIL14
BACK_BUS: MA07-2_BACKSIDEFRONTSIDE; MA07-2
BACK_BUS2: MA03-2
BACK_PWR: MA03-2
BUFFER1, BUFFER2: 4050; DIL16
C5, C6: 10uf; CPOL-RADIAL-10UF-25V
D5, D6: 1N4001; DO41-10
F1, F2: FUSE; C050H075X075
FRONT_BUS: MA07-2_BACKSIDEBACKSIDE; MA07-2_BACKSIDE
FRONT_BUS2: MA03-2BACKSIDE
FRONT_PWR: MA03-2BACKSIDE
GATES: MA08-2
L1, L2: BL01RN1A
PULSES: MA08-2
SV1: 10_PIN_HEADER; MA05-2

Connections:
+12V_BACK: BACK_PWR.5, BACK_PWR.6, C5.1 (+), GATES.15, GATES.16, L1.2, PULSES.15, PULSES.16; also elsewhere on the board
+12V_FRONT: FRONT_PWR.5, FRONT_PWR.6; also elsewhere on the board
+12V_INLET: D5.C, F1.1, SV1.9, SV1.10
-12V_BACK: BACK_PWR.1, BACK_PWR.2, C6.2 (-), GATES.11, GATES.12, L2.2, PULSES.11, PULSES.12; also elsewhere on the board
-12V_FRONT: FRONT_PWR.1, FRONT_PWR.2; also elsewhere on the board
-12V_INLET: D6.A, F2.1, SV1.1, SV1.2
B1_BACK: AND_2.8 (I0), BACK_BUS.1, BUFFER2.9 (I); also elsewhere on the board
B1_FRONT: FRONT_BUS.1; also elsewhere on the board
B2_BACK: AND_2.13 (I1), BACK_BUS.2, BUFFER2.11 (I); also elsewhere on the board
B2_FRONT: FRONT_BUS.2; also elsewhere on the board
B3_BACK: AND_2.5 (I0), BACK_BUS.3, BUFFER2.7 (I); also elsewhere on the board
B3_FRONT: FRONT_BUS.3; also elsewhere on the board
B4_BACK: AND_2.1 (I0), BACK_BUS.4, BUFFER2.5 (I); also elsewhere on the board
B4_FRONT: FRONT_BUS.4; also elsewhere on the board
B5_BACK: AND_1.12 (I0), BACK_BUS.5, BUFFER1.11 (I); also elsewhere on the board
B5_FRONT: FRONT_BUS.5; also elsewhere on the board
B6_BACK: AND_1.8 (I0), BACK_BUS.6, BUFFER1.9 (I); also elsewhere on the board
B6_FRONT: FRONT_BUS.6; also elsewhere on the board
B7_BACK: AND_1.5 (I0), BACK_BUS.7, BUFFER1.7 (I); also elsewhere on the board
B7_FRONT: FRONT_BUS.7; also elsewhere on the board
B8_BACK: AND_1.1 (I0), BACK_BUS.8, BUFFER1.5 (I); also elsewhere on the board
B8_FRONT: FRONT_BUS.8; also elsewhere on the board
BUFFCLK2_BACK: AND_1.2 (I1), AND_1.6 (I1), AND_1.13 (I1), BUFFER1.2 (O)
BUFFCLK_BACK: AND_1.9 (I1), AND_2.2 (I1), AND_2.6 (I1), AND_2.9 (I1), AND_2.12 (I0), BUFFER2.2 (O), GATES.9, GATES.10, PULSES.9, PULSES.10
CLOCK_BACK: BACK_BUS.9, BUFFER1.3 (I), BUFFER2.3 (I); also elsewhere on the board
CLOCK_FRONT: FRONT_BUS.9; also elsewhere on the board
END_OF_LOOP_BACK: BACK_BUS2.6; also elsewhere on the board
END_OF_LOOP_FRONT: FRONT_BUS2.6; also elsewhere on the board
GATE1: BUFFER2.10 (O), GATES.1
GATE2: BUFFER2.12 (O), GATES.2
GATE3: BUFFER2.6 (O), GATES.3
GATE4: BUFFER2.4 (O), GATES.4
GATE5: BUFFER1.12 (O), GATES.5
GATE6: BUFFER1.10 (O), GATES.6
GATE7: BUFFER1.6 (O), GATES.7
GATE8: BUFFER1.4 (O), GATES.8
GND_BACK: BACK_PWR.3, BACK_PWR.4, BUFFER1.14 (I), C5.2 (-), C6.1 (+), D5.A, D6.C, GATES.13, GATES.14, PULSES.13, PULSES.14, SV1.3, SV1.4, SV1.5, SV1.6, SV1.7, SV1.8; also elsewhere on the board
GND_FRONT: FRONT_PWR.3, FRONT_PWR.4; also elsewhere on the board
LOOP_CTRL_BACK: BACK_BUS2.4; also elsewhere on the board
LOOP_CTRL_FRONT: FRONT_BUS2.4; also elsewhere on the board
unnamed: F1.2, L1.1
unnamed: F2.2, L2.1
NOISE_BACK: BACK_BUS2.1; also elsewhere on the board
NOISE_FRONT: FRONT_BUS2.1; also elsewhere on the board
PULSE1: AND_2.10 (O), BUFFER2.14 (I), PULSES.1
PULSE2: AND_2.11 (O), PULSES.2
PULSE3: AND_2.4 (O), PULSES.3
PULSE4: AND_2.3 (O), PULSES.4
PULSE5: AND_1.11 (O), PULSES.5
PULSE6: AND_1.10 (O), PULSES.6
PULSE7: AND_1.4 (O), PULSES.7
PULSE8: AND_1.3 (O), PULSES.8
PULSE_OUT_BACK: BACK_BUS.10, BUFFER2.15 (O)
PULSE_OUT_FRONT: FRONT_BUS.10; also elsewhere on the board
START_OF_LOOP: BACK_BUS2.5; also elsewhere on the board
STEP_12_BACK: BACK_BUS2.3; also elsewhere on the board
STEP_12_FRONT: FRONT_BUS2.3; also elsewhere on the board
STEP_16_BACK: BACK_BUS2.2; also elsewhere on the board
STEP_16_FRONT: FRONT_BUS2.2; also elsewhere on the board
WRITE_SW_FRONT: FRONT_BUS2.5; also elsewhere on the board

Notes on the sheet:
Optional reverse polarity protection If not required, omit diodes and replace fuses with jumper wire. Don't get it the wrong way around! Ferrites: 81-BL01RN1A1D2B or 623-2743001112LF
Channels between front and back: GND +12V -12V STEP_16_FRONT - STEP_16_BACK STEP_12_FRONT - STEP_12_BACK CLOCK_FRONT - CLOCK_BACK END_OF_LOOP_FRONT - END_OF_LOOP_BACKRL LOOP_CTRL_FRONT - LOOP_CTRL_BACK WRITE_SW_FRONT - START_OF_LOOP B1(-B8)_FRONT - B1(-B8)_BACK

Board: 4 copper layers, 111 parts (3 on the bottom side), 104 nets, no tracks yet.

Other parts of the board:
U$1, U$3, U$4, U$5: MOUNTING_HOLE

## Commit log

2015-03-14 Upload rev4 build
    [TuringMachine.brd, TuringMachine.sch]
2015-03-14 Laid out & routed board with rotary switch
    Need to print and check
    [TuringMachine.brd, TuringMachine.sch]
2015-03-16 Hand routing
    [TuringMachine.brd, TuringMachine.sch]
2015-03-16 manual routing
    [TuringMachine.brd, TuringMachine.sch]
2015-03-18 Prototype 1 complete and sent to OSHPark
    [TuringMachine.brd, TuringMachine.sch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]
2015-04-11 Added BOM
    [Turing v4 Mouser Export.xls, TuringMachine.brd, TuringMachine.sch]
2015-07-22 Update R32 in noise and R6 in CV input
    [TuringMachine.brd, TuringMachine.sch]
2015-07-25 Move R16 & C4 to start of loop
    [TuringMachine.brd, TuringMachine.sch]
2015-07-25 Remove transistors, replace with 4016 gates
    [TuringMachine.brd, TuringMachine.sch]
2015-07-25 Fixes #5, fixes #4
    [TuringMachine.brd, TuringMachine.sch]
2015-07-25 not yet routed
    [TuringMachine.brd, TuringMachine.sch]
2015-08-19 starting to complete dual pcb schematic
    [TuringMachine.brd, TuringMachine.sch]
2015-08-20 schematic splitting
    [TuringMachine.brd, TuringMachine.sch]
2015-08-22 add 100k resistor after noise comparator
    [TuringMachine.brd, TuringMachine.sch]
2015-08-26 Adding pulse out
    [TuringMachine.brd, TuringMachine.sch]
2015-08-26 Before board split
    [TuringMachine.brd, TuringMachine.sch]
2015-08-28 Back board routed!
    [TuringBack.brd, TuringBack.sch, TuringFront.brd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]
2015-08-29 Starting to route front board
    [TuringBack.brd, TuringBack.sch, TuringFront.brd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]
2015-09-13 routing tweaks on back panel
    [TuringBack.brd, TuringFront.brd, TuringFront.sch]
2015-09-13 Front board routed awaiting checking and optimisation
    [TuringFront.brd, TuringFront.sch]
2015-09-13 tidy up schematics
    [TuringBack.sch, TuringFront.sch]
2015-09-14 Create Panel
    Placed holes - need to move and create board size pcb
    [TuringPanel.brd, TuringPanel.sch]
2015-09-17 fix sizing and add mounting holes
    [TuringPanel.brd]
2015-09-18 Completed panel
    Gold on matte
    [TuringPanel.brd]
2015-09-24 clean up front layout
    [TuringFront.brd]
2015-09-25 cosmetic routing changes
    [TuringFront.brd]
2015-09-27 Routing tweaks
    [TuringBack.brd, TuringFront.brd]
2015-09-27 Finalised Designs + Gerbers
    First prototype for two-board design with PCB panel and built in
    Backpack
    [TuringMachine_singleBoard.brd, TuringMachine_singleBoard.sch, TuringPanel.brd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]
2015-10-23 pot values
    [TuringFront.brd, TuringFront.sch]
2015-11-01 Add rotary switch pic
2016-01-03 Cosmetic changes to IC appearance
    Fixes #17, Fixes #13
    [TuringBack.brd, TuringBack.sch, TuringFront.brd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]
2016-01-03 minor rerouting
    Fixes #22, fixes #21
    [TuringFront.brd]
2016-01-03 Rev 4 Front and Back Boards complete
    [TuringBack.brd, TuringBack.sch, TuringFront.brd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]
2016-01-03 Trimmer hole Fixes #19
    [TuringPanel.brd]
2016-01-04 Panel tweaks
    [TuringPanel.brd]
2016-01-12 Finalised V4 PCBs
    [TuringBack.brd, TuringFront.brd, TuringFront.sch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]
2016-01-22 Silkscreen change on Back Board
    Added + - symbols to fuses in power supply
    [TuringBack.brd, TuringBack.sch]
2016-01-27 Update front board to fix error in ground plane
    [TuringFront.brd]
2016-02-23 Front board updated with new Write switch component
    Slightly enlarged holes to accommodate 2.03 x 0.76 solder tags
    [TuringFront.brd, TuringFront.sch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]
2016-02-29 Front board silkscreen change: tidy up new switch markings
    [TuringFront.brd]
2016-03-19 Schematic fixed, back board needs to be routed
    [TuringBack.brd, TuringBack.sch]
2016-03-19 routing started
    [TuringBack.brd]
2016-03-20 First fully routed
    [TuringBack.brd, TuringBack.sch]
2016-03-20 Finished routing + gerber uploaded
    [TuringBack.brd, TuringBack.sch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]
2016-04-06 Folder changes
    [pinlist.xlsx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]
2016-04-07 draft moms
    [Turing v4 Mouser Export.xls]
2016-05-28 Upload Schematic PDF
    Closes #27
2017-02-19 removing old BOM
    [Turing v4 Mouser Export.xls]
2020-03-22 ignore CAM output in Hardware/ directory
    I generated my own TM Gerbers, for reasons I've long since forgotten,
    and they ended up in the Hardware directory. There's no reason to commit
    them, so don't.
    Thanks for sharing this wonderful project. <3

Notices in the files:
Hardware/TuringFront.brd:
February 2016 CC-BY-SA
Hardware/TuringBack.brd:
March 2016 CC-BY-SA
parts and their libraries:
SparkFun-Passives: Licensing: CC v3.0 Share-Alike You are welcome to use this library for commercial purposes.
